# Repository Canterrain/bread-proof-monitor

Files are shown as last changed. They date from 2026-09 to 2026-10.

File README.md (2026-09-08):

# Bread Proof Monitor

A dough rise monitor that helps you know when it's time to fold, shape, or bake.

Place the sensor over your dough, choose a bread profile, and follow the rise from your phone. The monitor keeps track of progress, reminds you about folds, and can send a notification when your dough reaches its target.

Built for an ESP32 with a distance sensor and a temperature and humidity sensor. The dashboard runs on the monitor itself and opens in a browser on your home network.

## ✨ Features

- Live dough rise, elapsed time, temperature, and humidity
- Profiles for everyday breads, sourdough, pizza, rolls, and more
- Links to the recipes the profiles are based on
- Fold reminders for recipes with handling steps
- Separate bulk and final proof targets
- Optional phone alerts through ntfy: fold reminders, Ready to Shape, and Ready to Bake
- Pause and resume while you handle the dough
- Feedback that adjusts future targets for your recipe and setup
- Wi-Fi setup from your phone, with no credentials to put in the code
- Installation over USB from your browser

The targets are starting points. Flour, hydration, temperature, and starter or yeast strength all affect a proof. Use the reading alongside how your dough looks and feels.

## 🛠 Hardware

This project is designed around these specific boards and sensor modules:

- [ELEGOO 3PCS ESP-32 Dev Boards](https://amzn.to/46aN2Hq) (affiliate; one board needed)
- [HiLetgo SHT31-D Temperature and Humidity Sensor](https://amzn.to/4xLTMYm) (affiliate)
- [VL53L0X Time-of-Flight Ranging Sensor](https://amzn.to/4xEbyg1) (affiliate)

You'll also need:

- A USB data cable and USB power supply
- A container, and something that holds the distance sensor above the dough

That mount can be as simple as it sounds: the working prototype this project was developed on is just jumper-wired breakouts hot-glued or taped into a lid, on a stand of legs for containers that need one. No PCB is required to build or use this project.

The browser installer is for the original ESP32 chip. ESP32-C3, S3, and P4 boards need different firmware.

### Wiring

Both sensors share the same I²C bus:

| ESP32 | VL53L0X breakout | SHT31 breakout |
| --- | --- | --- |
| 3V3 | VIN / VCC | VIN / VCC |
| GND | GND | GND |
| **GPIO22** | **SDA** | **SDA** |
| **GPIO21** | **SCL** | **SCL** |

Use the pin labels on your particular breakout. This project's SDA and SCL assignments differ from the usual ESP32 defaults.

Mount the distance sensor securely above the dough with room for the tallest expected rise. Keep the sensor as close as that clearance allows. A long distance above a thin layer of dough makes small measurement changes look like much larger changes in rise.

### Optional: Rev A Carrier PCB

If you'd rather not hand-wire and hot-glue sensors into a lid, a custom carrier PCB is available as a drop-in alternative to the wiring table above — plug-in sockets for the ELEGOO EL-SM-012, ALAMSCN VL53L0X-V2, and HiLetgo GY-SHT31-D modules replace the loose wiring entirely. It's entirely optional; the software doesn't know or care which mounting approach you used. Its [KiCad files and manufacturing package](hardware/kicad/rev-a/README.md) are included — see the [hardware guide](guides/hardware.md) for ordering and assembly steps. The lid and enclosure design is still in progress, so even with the PCB you'll still need your own way to mount it.

## 🚀 Quick Start

### Install the software

Use Chrome, Edge, or a Firefox version with Web Serial support on a desktop or laptop. Safari and mobile browsers aren't supported by this installer.

1. Plug the ESP32 into your computer with a USB **data** cable.
2. Open the **[Bread Proof Monitor installer](https://canterrain.github.io/bread-proof-monitor/)**.
3. Click **Connect**, choose your board, and select **Install**.
4. For a first installation, select **Erase device**. Wait for installation to finish and the board to restart.

You don't need Arduino IDE to use the browser installer. If you'd rather build it yourself, see the [build guide](guides/development.md).

### Connect to Wi-Fi

1. Open your phone or computer's **Wi-Fi settings** and join **ProofMonitor-Setup**. The password is **sourdough**.
2. Open [http://192.168.4.1](http://192.168.4.1).
3. Choose your home Wi-Fi network and enter its password.
4. If you want phone alerts, copy the generated ntfy topic and subscribe to it in the ntfy app.
5. Save, wait for the monitor to restart, and reconnect your phone or computer to your home network.
6. Open **[http://proofmonitor.local](http://proofmonitor.local)**.

If that address doesn't open, use the monitor's IP address from your router's connected-device list.

## Using the Monitor

Choose a profile and apply its target. With the empty container and lid in their normal positions, press **Set Empty Setup**. Add the dough, let the lid settle, then press **Set Starting Dough Height**.

The dashboard shows the rise, time, and next step. When a fold is due:

1. Press **Pause Monitoring** before lifting the lid.
2. Fold the dough and put the lid back.
3. Press **Resume Monitoring**, allow the reading to settle, then press **Complete Step**.

When the target is reached, check the dough before pressing **Finish Proof**. For profiles with a monitored final proof, the monitor then prepares the Final stage. Most profiles ask you to calibrate the empty final-proof setup again before setting a new starting height.

Some recipes finish with refrigerated rests or stages that aren't useful to track by height. The monitor tells you when to continue with the linked recipe.

The [usage guide](guides/usage.md) covers calibration, pauses, re-baselining, target confirmation, and starting another batch.

## 🔔 Phone Alerts

Alerts use [ntfy](https://ntfy.sh/). Subscribe to the topic shown during setup to get fold reminders and Ready to Shape or Ready to Bake notifications.

The monitor generates a random topic for you. Treat that topic like a private link: anyone who knows it can subscribe or send messages to it. The dashboard works locally; delivering phone alerts requires internet access.

## Learning Your Dough

After each stage, rate the dough **Underproofed**, **Just Right**, or **Overproofed**, based on what you saw when that stage finished.

Two matching underproofed or overproofed ratings move that recipe and stage's suggested target by five percentage points. Adjustments stay within 25 points of the original suggestion. A Just Right rating clears the streak and keeps the adjustment.

Your feedback is saved on the device. Learned targets are used when you select a profile and when the monitor prepares Final proof. A proof keeps the target you've already applied. **Reset Learned Targets** clears the stored adjustments.

## Updating

Reconnect the ESP32 to your computer and use the same browser installer. For an update from this project's existing 4 MB / Huge APP layout, leave **Erase device** unchecked to retain saved settings. Erasing clears Wi-Fi, calibration, progress, the ntfy topic, and learned targets; repeat first-time setup afterward.

Update between proofs. Wireless updates aren't included.

## Development

The firmware uses Arduino for ESP32. See the [development guide](guides/development.md) for dependencies, local builds, and how to prepare a new browser-installable version.

| Path | What's there |
| --- | --- |
| `bread_proof_monitor.ino` | Startup and main loop |
| `app_state.*`, `proof_state.*` | Saved settings, rise calculations, and proof steps |
| `sensor_reader.*` | Distance, temperature, and humidity readings |
| `recipe_presets.*`, `outcome_feedback.*` | Profiles and learned target adjustments |
| `web_dashboard.*`, `web_assets.h` | Dashboard and setup pages |
| `notifications.*`, `wifi_setup.*` | Phone alerts and Wi-Fi |
| `docs/` | GitHub Pages installer and firmware files |
| `guides/` | Usage, development, and publishing instructions |
| `hardware/` | Carrier PCB design and manufacturing files |
| `tools/` | Local build, upload, and firmware packaging tools |

## Related Projects

- [Round Weather Display](https://github.com/Canterrain/round-weather-display), a round clock and weather display for Raspberry Pi or ESP32-P4
- [Weather Display](https://github.com/Canterrain/weather-display), a wider clock and weather display for under a cabinet or on a desk
- [Inky Planner](https://github.com/Canterrain/Inky-Planner), a daily planner for Raspberry Pi and Inky e-paper displays

## 📃 License

This project is licensed under the [Creative Commons Attribution–NonCommercial 4.0 International License](https://creativecommons.org/licenses/by-nc/4.0/). See [LICENSE](LICENSE). Third-party libraries retain their own licenses.

© 2026 Josh Hendrickson

Made by [Josh Hendrickson](https://anoraker.com)

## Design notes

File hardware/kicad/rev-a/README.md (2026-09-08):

# Rev A Carrier PCB

Reference documentation for the Bread Proof Monitor carrier PCB: a small board that gives the ESP32 module and both sensor breakouts a rigid, repeatable mount on the underside of a lid, using plug-in sockets instead of loose wiring.

## Status

- Schematic and PCB are complete. ERC: 0 errors, 0 warnings. DRC: 0 errors, 1 accepted cosmetic warning (see [Exclusions](#exclusions)).
- Routed at conventional prototype design rules — 0.25 mm trace, 0.6 mm/0.3 mm via, 0.2 mm clearance. No relaxed tolerances.
- All PCB-affecting mechanical decisions are finalized (VL53L0X optical alignment, SHT31 retention approach — see `mechanical-stackup.md`).
- Gerbers, drill files, and the full manufacturing package are generated and ready to order — see [Manufacturing Package](#manufacturing-package).
- Not yet designed: the lid/enclosure itself. Nothing here depends on it; see `mechanical-stackup.md` for the parametric interface (optical bore, vent pocket, standoff heights) it will need to satisfy.

## Bill of Materials

### Carrier-assembled (populated by the PCB assembly house)

| Ref | Part | Qty | Represents |
| --- | --- | ---: | --- |
| J1, J2 | Samtec `SSW-115-01-T-S` (1×15, 2.54 mm, THT) | 2 | Sockets the ELEGOO EL-SM-012 ESP32 module plugs into |
| J3 | Samtec `SSW-106-01-T-S` (1×6, 2.54 mm, THT) | 1 | Socket for the VL53L0X breakout |
| J4 | Samtec `SSW-104-01-T-S` (1×4, 2.54 mm, THT) | 1 | Socket for the SHT31 breakout |

J1 and J2 are the same physical part in two positions (a BOM grouped by MPN reports them as one line, qty 2). All four sockets are the same Samtec SSW family: 2.54 mm pitch, single-row, through-hole, lead-free (`-S`).

`U1` is a silkscreen/mechanical reference only for the ESP32 module's outline — zero pads, `in_bom=no`, `dnp=yes`. It never appears in a BOM export.

### User-installed (not part of the PCB order)

| Plugs into | Part | Amazon ASIN |
| --- | --- | --- |
| J1 + J2 | ELEGOO EL-SM-012 (ESP32 dev module) | B0D8T53CQ5 |
| J3 | ALAMSCN black VL53L0X-V2 breakout | B0DGL2P6XC |
| J4 | HiLetgo GY-SHT31-D breakout | B07ZSZW92J |

The EL-SM-012 plugs directly into J1/J2 using its own existing pin rows — nothing to solder. The VL53L0X-V2 and SHT31 breakouts (J3, J4) ship with loose 2.54 mm male header strips that need to be soldered onto the breakout before it plugs into the carrier.

## Pinout

### EL-SM-012 (ESP32 module) pin map

Verified directly against the [EL-SM-012 manual's pinout diagram](https://manuals.plus/asin/B0D8T53CQ5) (Section 5, Figure 5.1). Only the four pads below carry nets; the rest of the header exists for mechanical support only.

| Pad | Function | Pad | Function |
| ---: | --- | ---: | --- |
| 1 | VIN (5V) | 16 | **3V3** |
| 2 | **GND** | 17 | **GND** |
| 3 | GPIO13 | 18 | GPIO15 |
| 4 | GPIO12 | 19 | GPIO2 |
| 5 | GPIO14 | 20 | GPIO4 |
| 6 | GPIO27 | 21 | GPIO16 |
| 7 | GPIO26 | 22 | GPIO17 |
| 8 | GPIO25 | 23 | GPIO5 |
| 9 | GPIO33 | 24 | GPIO18 |
| 10 | GPIO32 | 25 | GPIO19 |
| 11 | GPIO35 | 26 | **GPIO21 (SCL)** |
| 12 | GPIO34 | 27 | GPIO3 (RX0) |
| 13 | GPIO39 (VN) | 28 | GPIO1 (TX0) |
| 14 | GPIO36 (VP) | 29 | **GPIO22 (SDA)** |
| 15 | EN | 30 | GPIO23 |

**Warning:** pad 1 is VIN — raw 5V from USB — not 3V3. Only pads 16 (3V3) and 17 (GND) feed the sensor rail; both sensors are 3.3V-only parts. All four connected pads (3V3, GND, SDA, SCL) sit on the same header column (16-30); the other column (1-15) carries no nets on this board.

The GPIO22 → SDA / GPIO21 → SCL assignment is a firmware convention, not a hardware requirement — it matches the wiring already used by the ESP32 sketch itself. The EL-SM-012's own silkscreen shows a different default for the Wire library; this board's net assignment intentionally overrides that default.

### Connector and mounting-hole reference

`LID_ORIGIN` (0, 0) is the geometric center of the dough/container reference plane, and doubles as `TOF_ORIGIN` — the VL53L0X's optical axis is placed exactly there by construction (J3 is rotated 180° so its optical center, not its mounting-hole midpoint, lands on the datum). Coordinates below are relative to `LID_ORIGIN`; +X toward the antenna notch, +Y toward the ESP32 header.

| Feature | Coordinate (mm) | Notes |
| --- | ---: | --- |
| J3 (VL53L0X) mounting holes | (-10, -2.2) / (+10, -2.2) | Hole-midpoint sits at (0, -2.2), not `LID_ORIGIN` — the sensor's actual optical axis is what's aligned to the datum instead |
| J4 (SHT31) footprint origin (pin 1 / VIN) | (0, -29) | Not a mechanical datum. Retention is a lid/enclosure pocket-clip, not a PCB feature |
| U1 (ESP32 module outline) footprint origin | (0, +27) | Mechanical reference only, not a BOM item |
| J1 / J2 (ESP32 carrier sockets) | (-17.78, +14.18) / (-17.78, +39.82) | Local pin 1 of each |
| MH1 / MH2 / MH3 (carrier mounting holes) | (+40, 0) / (-40, 0) / (0, -45) | 3.2 mm NPTH, M3 clearance, provisional pending host hardware |

## Board Outline

A circle with a USB-C access notch and an antenna overhang notch, rather than a plain circle or a custom polygon — a plain circle large enough to clear the ESP32 module would need to be bigger still and wouldn't give cable/antenna clearance on its own.

- **Base circle:** radius 52 mm, centered on `LID_ORIGIN`. Overall envelope: X/Y from -52.0 to +52.0 mm (~104 × 104 mm).
- **USB-C notch:** board material stops at X = -25 mm, open from there to the edge across Y = 17-37 mm. The EL-SM-012's USB-C connector sits just past this cut, fully in open air.
- **Antenna notch:** board material stops at X = +21 mm, open across the same Y range, 3.22 mm past J1/J2's last pin — giving the WROOM antenna genuine physical overhang rather than relying only on a copper keepout.
- The board's lower size bound is the EL-SM-012 module's own footprint (51.74 × 29.00 mm); its farthest structurally-needed corner sits 50.3 mm from `LID_ORIGIN`, leaving a 1.7 mm margin at the 52 mm radius.

## Antenna Clearance

- `ESP32_ANTENNA_KEEP_OUT`, on both F.Cu and B.Cu: X 9-65 mm, Y 15-39 mm (56 × 24 mm) — no tracks, vias, or zone fills permitted inside it.
- Board material itself ends at X = 21 mm (the antenna notch above), so this region has no FR4 at all, not just no copper.
- The SDA trace's closest approach (pad 29, local X = +15.24 mm) jogs into its routing lane above the header row before heading down the board, so it never enters the keepout's Y band.

## Routing

- **Shared trunks, not per-destination lanes.** 3V3, SDA, and SCL each get one trunk from J2, which tees off to J3 and continues to J4 — not a separate trunk per destination. This keeps routing to 3 lanes at conventional design rules.
- **GND has no explicit trace.** J2, J3, and J4's GND pads are through-hole and sit directly inside the filled F.Cu/B.Cu ground pours; three stitching vias tie the two copper layers together away from the signal corridor. Verified directly against KiCad's own connectivity graph (not inferred from geometry) — J2's GND pad and both sensors' GND pads resolve to the same connected copper network.
- All routing lives on B.Cu, with a handful of via hops to F.Cu to resolve a few crossings.
- 15 vias total: 12 signal-routing detour vias (3V3 ×8, SCL ×4, SDA ×0) plus 3 GND stitching vias. Minimum via-to-via spacing: 0.7 mm edge-to-edge.

## Mechanical Clearances

No copper or courtyard overlap anywhere on the board:

- J1 (top, nearest neighbor to J3) to J3 (bottom): 3.93 mm Y gap.
- J3 to J4 (both bottom): 4.60 mm Y gap.

## Exclusions

1. **Silkscreen clipped by the board edge** — U1's own reference outline rectangle on F.SilkS is clipped at the USB-C notch, since the real EL-SM-012 module genuinely overhangs that cutout by design. Cosmetic only; has no fabrication impact.

## Manufacturing Package

`RevA_Manufacturing_2026-08-26/` contains the complete fabrication and assembly output — Gerbers, Excellon drill files with maps and a report, the final assembly BOM, a placement/position file, a fabrication drawing, and `RevA_Gerbers_NextPCB.zip` (Gerbers + drill files pre-zipped for direct upload to NextPCB's quote tool). See that directory's own `README.md` for the full contents list, fabrication notes, and its change history.

## References

- [EL-SM-012 manual and dimensional drawing](https://manuals.plus/asin/B0D8T53CQ5) — pinout diagram in Section 5, Figure 5.1
- [HiLetgo GY-SHT31-D product listing, ASIN B07ZSZW92J](https://www.amazon.com/dp/B07ZSZW92J)
- [ALAMSCN VL53L0X-V2 product listing, ASIN B0DGL2P6XC](https://www.amazon.com/dp/B0DGL2P6XC)

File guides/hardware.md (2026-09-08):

# Ordering and Building the Carrier PCB

[Back to the project](../README.md)

This covers getting a Rev A carrier PCB made and turning it into a working sensor mount. For the board's full technical reference (pinout, dimensions, design rules, verification results), see [`hardware/kicad/rev-a/README.md`](../hardware/kicad/rev-a/README.md).

The lid and enclosure this carrier mounts into aren't designed yet, so this guide stops at a working, bench-wired sensor mount rather than a finished physical unit.

## 1. Order the PCB

The fabrication files are in [`hardware/kicad/rev-a/RevA_Manufacturing_2026-08-26/`](../hardware/kicad/rev-a/RevA_Manufacturing_2026-08-26/). It's a conventional 2-layer board at standard prototype tolerances — no special fabrication options are needed.

- **Bare board only:** upload `RevA_Gerbers_NextPCB.zip` (or the `gerbers/` and `drill/` folders directly) to your fab house's quote tool. You'll receive an unpopulated board and need to hand-solder the four sockets yourself — see the carrier-assembled parts table in [`hardware/kicad/rev-a/README.md`](../hardware/kicad/rev-a/README.md#bill-of-materials) (or `bom/RevA_assembly_BOM.csv` directly) for the exact Samtec part numbers.
- **Board with sockets pre-assembled:** if your fab offers PCB assembly (NextPCB does), upload the Gerbers/drill files for fabrication and also supply `bom/RevA_assembly_BOM.csv` and `position/RevA_placement.csv` for the assembly step. All four sockets are through-hole, so hand or wave soldering is the expected assembly method — a pick-and-place file has limited value here, but it's included for completeness.

Either way, you're only ordering and paying for the bare carrier board and its four sockets — the ESP32 module and both sensor breakouts are never part of this order.

## 2. Buy the plug-in modules

These are ordinary off-the-shelf parts, bought separately from wherever you like:

| Plugs into | Part | Amazon ASIN |
| --- | --- | --- |
| J1 + J2 | ELEGOO EL-SM-012 (ESP32 dev module) | B0D8T53CQ5 |
| J3 | ALAMSCN black VL53L0X-V2 breakout | B0DGL2P6XC |
| J4 | HiLetgo GY-SHT31-D breakout | B07ZSZW92J |

## 3. Prepare the sensor breakouts

The VL53L0X and SHT31 breakouts ship with loose 2.54 mm male header strips, not pre-soldered pins. Solder a header onto each one before it can plug into the carrier.

The EL-SM-012 needs no preparation — it already has its own male pin rows fixed to the module and plugs straight into J1/J2.

## 4. Assemble

1. Plug the EL-SM-012 into the J1/J2 sockets (top side of the carrier).
2. Plug the VL53L0X breakout into J3 (underside).
3. Plug the SHT31 breakout into J4 (underside), sensing element facing outward.

**Before powering on, double-check orientation on all three.** These are plain single-row headers into single-row sockets — nothing mechanically prevents a shifted or reversed insertion. Confirm each module's pin 1 lines up with its socket's pin 1 against the board's silkscreen. Getting this wrong on the ESP32 module in particular can put 5V (VIN) where the sensors expect 3.3V.

## 5. Mount to a lid

Carrier mounting holes MH1-MH3 (3.2 mm NPTH, M3 clearance) are in place for this, but the lid/enclosure design that uses them isn't finished. Until it is, this is a DIY step — see [`mechanical-stackup.md`](../hardware/kicad/rev-a/mechanical-stackup.md) for the parametric interface (optical bore, vent pocket, standoff heights) any lid design needs to satisfy, and the wiring table in the main [README](../README.md#wiring) for a non-PCB mounting approach in the meantime.

## 6. First power-up

Once assembled, treat it like any other Bread Proof Monitor board: follow the main README's [Quick Start](../README.md#-quick-start) to install the firmware over USB and connect it to Wi-Fi.

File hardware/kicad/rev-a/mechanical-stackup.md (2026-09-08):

# Rev A Mechanical Stack-up — Sensor Interfaces

Status: **Rev A PCB-affecting mechanical decisions are finalized.** The
VL53L0X optical XY alignment, SHT31 retention approach, and P_sensor
nominal are all settled and reflected in the fabricated copper (§1, §2,
§3). Lid thickness and enclosure geometry remain **parametric** — every
dimension that depends on the lid is still expressed as a formula, not a
fixed number, since the lid itself is not yet designed. Gerbers are
generated this pass; lid CAD is not.

**Hardware identities (established outside this task — used as-is, not
re-researched here):**

| Module | Exact part | Amazon ASIN |
| --- | --- | --- |
| ESP32 | ELEGOO EL-SM-012 | B0D8T53CQ5 |
| VL53L0X | ALAMSCN black VL53L0X-V2 | B0DGL2P6XC |
| SHT31 | HiLetgo GY-SHT31-D | B07ZSZW92J |

**Architecture note — removable plug-in modules, not soldered to the
carrier.** ESP32, VL53L0X, and SHT31 are all plug-in modules: female
Samtec SSW sockets are soldered to the carrier PCB (J1 + J2:
`SSW-115-01-T-S`, 1x15 each, one per ESP32 pin row; J3: `SSW-106-01-T-S`,
1x6; J4: `SSW-104-01-T-S`, 1x4 — 2.54 mm pitch, single-row, through-hole,
lead-free solderable). U1 itself is the ESP32 module's mechanical outline
only — zero pads, not a BOM/assembly item; the module is user-installed,
plugging into J1/J2, not procured or soldered by the assembly house. The
sensor-side male pins are the loose 2.54 mm
header strips already supplied with the exact ALAMSCN VL53L0X-V2 and
HiLetgo GY-SHT31-D modules — not a separately selected or premium
replacement part. Each breakout plugs into its socket and is additionally
mechanically retained by the M2.5 standoff/screw system (§3.1) — except
SHT31, which uses a lid/enclosure pocket-clip instead (§2.3, Rev 7). No
sensor board is soldered directly to the carrier.

**Rev 2 — corrections applied in that pass:** the VL53L0X optical bore is
no longer a precise Ø3.0 mm hole centered on the mounting-hole midpoint
(§1.5, historical); the Z-stack no longer lets a standoff "independently"
set the sensor board's height while the connector "just tolerates" it
(§3); `G_top`/`H_lid`/`D_far = G_top + H_lid` are defined separately, and
the bore is sized at `D_far`, not `G_top`.

**Rev 3 — corrections applied in that pass:** the mounting-hole midpoint
was no longer called `TOF_ORIGIN` while also being ~2.1 mm from the real
optical axis — three separate datums (`LID_ORIGIN`, `J3_MOUNT_ORIGIN`,
`TOF_ORIGIN`) are now named explicitly (§1.1); `P_sensor` (VL53L0X package
protrusion below the breakout board) was introduced so Standoff B accounts
for it (`Standoff_B_J3 = P_sensor + G_top`, `L_total_J3 = H_conn + t_board
+ P_sensor + G_top`), while `D_far = G_top + H_lid` stays unchanged since
it's already referenced from the optical face directly.

**Rev 4 — corrections applied in this pass:**

1. **Removed the unsupported `H_conn = 2.5 mm` assumption.** That number
   was a "low-profile socket" placeholder invented for lack of a selected
   part. It's gone. `H_conn` is now carried **symbolically** through every
   formula and worked example until the real connector-pair geometry is
   known (§3.0, §3.1).
2. **Named the current preferred carrier-side socket family**: Samtec
   `CES-106-01-G-S` (J3, 1×6) and `CES-104-01-G-S` (J4, 1×4) — 2.54 mm
   pitch, single-row, through-hole, closed-entry, low-profile. Their
   published mechanical drawing gives a **5.08 mm socket body height**.
3. **That body height is explicitly not `H_conn`.** `H_conn` is the
   carrier-PCB-underside-to-breakout-board-top distance *once the actual
   mating male header is fully and correctly seated* — a function of the
   male header's own geometry and insertion depth, not of the socket
   alone. Until a matching male header is selected, `H_conn` stays
   unresolved (§3.1).
4. Made every dependent Z-stack formula parametric in `H_conn` rather
   than substituting a specific value for it.

**Rev 5 — correction applied in this pass:**

5. **Removed the intentionally-undersized `Standoff A = H_conn − c`
   model.** A rigid M2.5-screw-clamped standoff cut deliberately shorter
   than the connector's own mated height isn't a tolerance mechanism —
   tightening the screw would have to flex a PCB, preload the connector's
   pins, or leave the stack not actually clamped, to close that gap.
   `Standoff_A_nominal = H_conn` now — the connector establishes the
   seated Z position, and the mechanical support nominally meets the
   breakout at that same plane, no built-in offset. Real tolerance
   accommodation (spacer tolerancing, a compliant washer, shoulder-style
   retention, a rocking-only clip, or similar) is left as an open
   mechanical-detail decision, not invented here (§3.1).
6. **Corrected the framing of the remaining connector task.** The sensor
   breakouts already carry standard 2.54 mm male header interfaces — the
   HiLetgo GY-SHT31-D ships with its own male header strip soldered to the
   board, and the VL53L0X breakout's footprint already reflects the same
   kind of standard header pins. There is no header *family* left to
   choose. What remains is establishing the **actual mated geometry**
   (and the resulting `H_conn`) between those standard pins and the
   carrier-side socket (§3.1).

**Rev 6 — connector decision finalized, this pass:**

7. **Selected carrier-side sockets: Samtec SSW, not CES.** The Rev 4/5
   Samtec CES consideration is superseded. The selected parts are
   `SSW-115-01-T-S` (J1 + J2, 1x15 each, qty 2 — one per ESP32 pin row;
   U1 itself is the ESP32 module's mechanical outline, not a socket),
   `SSW-106-01-T-S` (J3, 1x6), and `SSW-104-01-T-S` (J4, 1x4) — 2.54 mm
   pitch, single-row, through-hole, lead-free solderable (`-S` row
   option). Sensor-side male pins are the loose header strips already
   supplied with the ALAMSCN VL53L0X-V2 and HiLetgo GY-SHT31-D modules —
   no replacement premium header, per instruction, unless a real fit
   problem is found.
8. **`H_conn` is resolved: `H_conn_nominal = 11.05 mm`** for the selected
   SSW stack (J3/J4). This number comes from the connector-stack decision
   made outside this document, not re-derived here. `Standoff_A_nominal =
   H_conn = 11.05 mm` (§3.1) — no longer symbolic. Everything downstream
   (`Standoff_B_J3`, `L_total_J3`) is now a concrete worked example, not
   an illustrative placeholder.
9. **KiCad footprints checked against the Samtec SSW/SSQ published
   mechanical drawing** (2.54 mm pitch; body length = `2.54mm x N +
   0.51mm`) and against KiCad's own verified standard 2.54 mm THT
   pin-socket land pattern (1.0 mm drill). The existing generic J3 and J4
   footprints were found dimensionally correct as-is — reused, not
   replaced. The former combined `ESP32_EL_SM_012_CARRIER_2x15` footprint
   (30 pads, doubling as both the ESP32 module's mechanical outline and
   its two real carrier sockets) was subsequently split — in the
   follow-on BOM-model cleanup, not re-derived here — into
   `ESP32_EL_SM_012_MODULE_OUTLINE` (U1: mechanical-only, zero pads, not
   a BOM item) plus two placements of a new `SSW-115-01-T-S_1x15`
   footprint (J1, J2: the real carrier sockets), at the exact same pad
   coordinates the combined footprint used. See
   `RevA_Sensors.pretty/*.kicad_mod` `descr` fields and the PCB build for
   the specific numbers checked, and the project README's "BOM model"
   section for the full J1/J2/U1 rationale.

**Rev 7 — Rev A PCB-affecting decisions finalized, this pass:**

10. **VL53L0X optical XY alignment resolved: `TOF_ORIGIN = LID_ORIGIN` by
    construction, not by hoping the offset is small.** The Rev A nominal
    optical offset is set to **2.2 mm** (the ALAMSCN listing-photo
    measurement of 2.12 mm, §1.2, corroborated by an independent direct
    measurement of a common GY-VL53L0XV2 board). Rather than shifting J3
    by +2.2 mm in Y — which would have moved it *toward* J1 and eaten
    into the ~1.7 mm J1/J3 courtyard clearance that existed at the time —
    J3 is **rotated 180°** and placed so its mounting-hole midpoint moves
    to `Y = -2.2 mm`, landing the *optical* axis on `LID_ORIGIN` instead.
    Footprint origin `(10, -2.2)`, rotation `180°`. Verified against
    KiCad's own applied transform, not just hand-derived (§1.3): resulting
    `J3_MOUNT_ORIGIN = (0, -2.2)`, `TOF_ORIGIN = (0, ~0) = LID_ORIGIN`,
    mounting holes at `(+10, -2.2)` and `(-10, -2.2)`. A side effect of
    the rotation (not just the shift) is that J3's courtyard now sits
    *farther* from J1 than before (§3.2/README), not closer — the
    original concern is fully addressed, not just avoided.
11. **SHT31 retention resolved: lid/enclosure pocket-clip, not a PCB
    hole.** Rev A does not add a carrier PCB retention hole for J4; the
    footprint's `PRELIM: VERIFY RETENTION HOLE` fab annotation and its
    associated candidate-hole graphic are removed (they no longer apply
    and would misleadingly imply PCB fabrication depends on them). J4's
    board envelope and socket geometry are otherwise unchanged (§2.3).
12. **`P_sensor` finalized as a Rev A nominal, not a PCB hold.**
    `P_sensor_nominal = 1.0 mm` (ST's published VL53L0X package height —
    the package is `4.4 × 2.4 × 1.0 mm`). Normal solder/assembly
    tolerance around this value is an enclosure/standoff tolerance
    question, not something that affects Rev A copper or placement.
13. **Breakout PCB thickness (`t_board`) reclassified as an
    enclosure-fit parameter, not a PCB hold** — it was never part of Rev A
    copper or placement, only of the (still-parametric, still-undesigned)
    lid/standoff stack-up.
14. **The PCB fabrication-hold list is now empty.** See "Remaining
    fabrication holds" below — everything that used to block Gerber
    generation is resolved. What's left are enclosure/mechanical
    fit-check items that the lid design will eventually want, none of
    which hold this PCB.

## 1. VL53L0X-V2 (J3) — optical package location

### 1.1 Datums — three separate points, now two of them coincide by design

This design has three distinct reference points that must not be
conflated, even though (as of Rev 7) two of them are now deliberately
made to coincide:

| Datum | Meaning | Current value | Status |
| --- | --- | --- | --- |
| **`LID_ORIGIN`** | The intended measurement point over the dough — the fixed reference everything else is judged against. | `(0, 0)` | Fixed, by definition — doesn't move. |
| **`J3_MOUNT_ORIGIN`** | Midpoint of J3's two M2.5 retention holes (20.0 mm apart). | `(0, -2.2)` | **Fixed by the Rev 7 footprint placement** (origin `(10,-2.2)`, rotation `180°`). No longer coincident with `LID_ORIGIN` — that trade was made deliberately so the *optical* axis, not the hole-midpoint, lands on the datum that actually matters. |
| **`TOF_ORIGIN`** | The VL53L0X's actual optical (emitter/receiver) axis. | `≈ (0, 0) = LID_ORIGIN` | **Achieved by construction (Rev 7)**, using the 2.2 mm Rev A nominal offset (§1.2/§1.3). Nominal, not caliper-verified against the exact physical part in hand — but no longer a PCB-blocking hold; residual error, if any, is well within the lid opening's built-in margin (§1.4). |

**Rev A achieved state** (verified against KiCad's own applied
position+rotation transform, not just hand-derived — §1.3):

```
J3_MOUNT_ORIGIN = (0, -2.2)          -- no longer at LID_ORIGIN
TOF_ORIGIN      = (0, ~0) = LID_ORIGIN   -- this is what's aligned now
```

Sections 1.4 onward say `TOF_ORIGIN` when they mean the optical axis and
`LID_ORIGIN`/`J3_MOUNT_ORIGIN` when they mean the fixed measurement point
or the hole geometry — the three are still not interchangeable, even
though `TOF_ORIGIN` and `LID_ORIGIN` now coincide.

- **Fixed by the footprint (exact):** the two M2.5 retention holes are
  20.0 mm apart. As of Rev 7 their midpoint (`J3_MOUNT_ORIGIN`) sits at
  `(0, -2.2)`, not at `LID_ORIGIN`. The two-hole rigid retention itself
  (geometry, hole size) is unchanged — only where it's placed moved.
- **Measured (§1.2):** the VL53L0X module's package outline position
  relative to those two holes, from the ALAMSCN listing's own product
  photography — this is what located `TOF_ORIGIN` and set the 2.2 mm Rev
  A nominal.
- **Still nominal, not caliper-verified:** the exact optical
  (emitter/receiver) centroid *within* the package outline. ST's VL53L0X
  datasheet gives the package size precisely (4.40 x 2.40 x 1.00 mm,
  "Optical LGA12") but does not publish the emitter/collector centroid
  offset from the package edge as a text-extractable dimension. Treating
  the package's geometric center as `TOF_ORIGIN` is a reasonable
  approximation, corroborated by an independent measurement of a common
  GY-VL53L0XV2 board — good enough confidence to commit to fabrication,
  not the same as a caliper/microscope measurement of the exact part in
  hand.

### 1.2 Measured offset from the ALAMSCN listing photos

The ALAMSCN listing (ASIN B0DGL2P6XC) product photography includes a
straight-on shot of the sensor-chip side of the board, silkscreened
`VL53L0/1XV2`, with a white rectangle marking the sensor module's own
footprint. Both mounting holes and the rectangle are clearly resolved.
Measuring directly from that image (hole spacing = 20.0 mm used as the
pixel-to-mm scale reference):

| Quantity | Value |
| --- | ---: |
| Measured module outline size | 4.92 x 2.83 mm (vs. ST's nominal 4.40 x 2.40 mm package — consistent, silkscreen courtyard is drawn slightly oversized) |
| `TOF_ORIGIN`, X, relative to `J3_MOUNT_ORIGIN` (pre-Rev-7 hole placement) | **-0.09 mm** (i.e. centered — within measurement noise) |
| `TOF_ORIGIN`, Y, relative to `J3_MOUNT_ORIGIN` (pre-Rev-7 hole placement) | **-2.12 mm** (offset away from the 6-pin header, toward the "blank" end of the board) |

In the footprint's own local frame (holes at local (0,0)/(20,0), header
pins at local Y=+5.35): `TOF_ORIGIN` sits at approximately local
**(10, -2.1)** — i.e. right at `J3_MOUNT_ORIGIN` in X, and about 2.1 mm
toward the header-free end in Y. **Rev A nominal, used for the placement
in §1.3, rounds this to 2.2 mm**, corroborated by an independent direct
measurement of a common GY-VL53L0XV2 board (not the exact ALAMSCN part,
but close geometry, done outside this document).

**Confidence:** this is measured from the exact listing's photography
(not a generic proxy board), so it's a real, specific data point — but it
is still a photo measurement, not a caliper or microscope measurement of
the physical part. Two independent sources now agree closely enough to
commit to fabrication (Rev 7) — see the fabrication-holds list for the
residual, non-blocking follow-up.

### 1.3 Rev A implementation — J3 rotated 180°, `TOF_ORIGIN` on `LID_ORIGIN`

**The problem with the obvious fix.** The naive correction — shift J3 by
+2.2 mm in Y, leaving its orientation alone — moves `J3_MOUNT_ORIGIN` (and
therefore J3's whole footprint, including its courtyard) *north*, i.e.
*toward* J1 (the ESP32 carrier socket immediately above it). At the time
this decision was made the J1/J3 courtyard gap was only ~1.7 mm; a
straight +2.2 mm shift would have consumed all of that margin and then
some. **Rejected for that reason.**

**The Rev 7 fix: rotate 180°, don't just translate.** The footprint's
local geometry is fixed: mounting holes at local `(0,0)` and `(20,0)`,
`J3_MOUNT_ORIGIN` at local `(10,0)`, optical package (`TOF_ORIGIN`) at
local `(10,-2.2)` (§1.2's measurement, rounded to the Rev A nominal).
Placing the footprint origin (anchor = local `(0,0)`) at global `(10,
-2.2)` with a `180°` rotation:

```
rotated_local(x,y) = (-x,-y)                     [180° about the anchor]
global(p)          = anchor + rotated_local(p)

J3_MOUNT_ORIGIN  (local 10,0):    (10,-2.2) + (-10, 0)  = (0, -2.2)
TOF_ORIGIN       (local 10,-2.2): (10,-2.2) + (-10, 2.2) = (0, 0)  = LID_ORIGIN
hole 1 (local 0,0):               (10,-2.2) + (0, 0)     = (10, -2.2)
hole 2 (local 20,0):              (10,-2.2) + (-20, 0)   = (-10, -2.2)
```

**Verified against KiCad's own applied transform after placement, not
just this hand derivation** — independently reconstructing pcbnew's
actual position+orientation transform and mapping the same local points
through it:

```
placed footprint anchor:  (10.0, -2.2) mm, orientation 180.0°
hole 1 (actual pad):      (10.0, -2.2) mm
hole 2 (actual pad):      (-10.0, -2.2) mm
J3_MOUNT_ORIGIN (midpoint of actual holes): (0.0, -2.2) mm
TOF_ORIGIN (local (10,-2.2) mapped through the SAME transform): (0.0, ~0.0) mm
```

The optical axis lands on `LID_ORIGIN` to floating-point precision. A
useful side effect of rotating (not just translating): J3's courtyard
shape is now oriented the *other* way too, so the net result is J3 moved
*away* from J1 overall (courtyard gap grew, §3.2/README), not toward it —
the original concern that ruled out the naive shift doesn't apply to the
rotation.

**Pin mapping is unaffected by the rotation.** J3's pin-to-net assignment
is a schematic-level fact, untouched by this PCB-only placement change:
pin 1 = 3V3, pin 2 = GND, pin 3 = SCL/GPIO21, pin 4 = SDA/GPIO22, pin 5
(GPIO1) and pin 6 (XSHUT) = NC. Only the physical *location* of those pins
moved (and, because of the 180° rotation, their X-ordering reversed and
their row moved from the north side of the mount holes to the south side)
— routing was rerouted to reach the new positions (README "Routing"), but
no net assignment changed.

### 1.4 Rev A final lid opening geometry

Three separate lengths matter here, and they must not be conflated:

- **`G_top`** — air gap from the sensor's optical face (`TOF_ORIGIN`)
  down to the lid's **top** (near, sensor-side) surface.
- **`H_lid`** — lid thickness (parametric, independent material choice).
- **`D_far = G_top + H_lid`** — distance from `TOF_ORIGIN` down to the
  lid's **chamber-side (far)** surface.

VL53L0X full field of view is **25°** (ST datasheet: "VL53L0X system FOV
is 25 degrees" / half-angle 12.5°), unchanged by cover glass choice (see
1.6). For a straight cylindrical bore of constant diameter, the FOV cone
is widest at the **far** end, so `D_far` — not `G_top` — is what must size
the bore:

```
opening_diameter(H_lid) = 2 · D_far · tan(12.5°) + margin
                         = 2 · (G_top + H_lid) · tan(12.5°) + margin
```

using `G_top = 1.5 mm` (target) and `margin = 1.0 mm` total:

| H_lid | D_far = G_top + H_lid | Bore Ø (centered exactly on `LID_ORIGIN`, = `TOF_ORIGIN` as of Rev 7) |
| ---: | ---: | ---: |
| 2.0 mm | 3.5 mm | 2.6 mm |
| **3.0 mm** | **4.5 mm** | **3.0 mm** |
| 4.0 mm | 5.5 mm | 3.4 mm |
| 5.0 mm | 6.5 mm | 3.9 mm |

**This is now the live spec, not a conditional future one.** Because J3
is physically rotated/repositioned so `TOF_ORIGIN = LID_ORIGIN` (§1.3),
this bore can be cut centered on `LID_ORIGIN` directly — the earlier
"provisional oversized opening, offset from `LID_ORIGIN`" approach (old
§1.5, kept below as historical record) is superseded and no longer
needed. This table does not depend on `H_conn` at all — the optical-bore
sizing and the connector question are independent.

**Recommendation: minimize `G_top`.** A small `G_top` keeps `D_far` (and
therefore the bore) small — good for a clean chamber-facing surface, a
minimal steam/condensate ingress path, and a short response time. Target
**`G_top` = 1.5 mm**.

### 1.5 Historical: the pre-Rev-7 provisional opening (superseded)

Before Rev 7, the PCB kept `J3_MOUNT_ORIGIN = LID_ORIGIN` and `TOF_ORIGIN`
was ~2.1-2.2 mm away, unresolved. Because a final-spec bore's own radius
(~1.5 mm) was smaller than that offset, a precision bore centered on
`LID_ORIGIN` would have risked missing the sensor's real field of view —
so two placeholder options were defined for a first fit-check lid only:
**Option A**, an oversized (~Ø5.0 mm at `H_lid`=3mm) opening centered on
the *estimated* `TOF_ORIGIN` rather than `LID_ORIGIN`; **Option B**, a
fully direction-agnostic Ø9.5 mm opening centered on `LID_ORIGIN` for a
team unwilling to trust even the measured offset's direction. **Both are
superseded by Rev 7** (§1.3/1.4) — `TOF_ORIGIN` now *is* `LID_ORIGIN` by
construction, so the final-spec bore (§1.4) applies directly. Kept here
only as a record of the reasoning that preceded the Rev 7 fix.

### 1.6 Cover glass — avoid unless necessary

Per the brief, default to **no cover** over the VL53L0X opening — a bare
through-hole, open to the chamber:

- **Ranging offset shift.** ST's guidance: a cover window changes the
  ranging offset and needs recalibration.
- **Cross-talk.** A cover glass reflects some VCSEL output back into the
  receiver, reducing usable range.

**When a cover would become necessary:** if condensation or flour dust
ingress into the electronics bay turns out to be a real problem. If so,
the fix is a thin (0.5-1 mm) IR-transparent window bonded at the lid's
chamber-side surface, sized to the bore diameter from 1.4, with the
offset/cross-talk recalibration noted as a required follow-up. Open
decision, not resolved here.

## 2. SHT31 (J4) — ventilated pocket, lid/enclosure retention

J4 is the exact **HiLetgo GY-SHT31-D (ASIN B07ZSZW92J)** established for
this project — not re-researched or substituted in this pass.

### 2.1 Location — unchanged

J4 stays at its established placement (footprint origin / pin 1 / VIN at
**(0, -29)** relative to `LID_ORIGIN`), clear of the VL53L0X optical path
and clear of J3's hardware by a de-risked margin (recomputed against the
Rev 7 J3 placement — see README "Mechanical: top vs. bottom overlap" for
the current J3/J4 clearance number). No placement change in this pass.

### 2.2 Ventilated pocket concept

The SHT31's sensing element is a capacitive RH + temperature die on the
underside of the small breakout board — unlike the VL53L0X, it has no
aiming requirement, just needs representative chamber air to reach it
without pooling condensate on the die. Proposed pocket, sized to the
board's real outline (10.7 x 13.1 mm per the existing footprint
annotation):

- A shallow rectangular **recess** in the lid's chamber-side face, sized
  to the board's real outline plus ~0.5 mm clearance per side, deep enough
  to seat the board's retention feature (see 2.3) flush or slightly
  recessed — not proud of the lid.
- **Vent pattern**, not a single large opening: 6-8x Ø1.5 mm holes
  positioned under the sensing-element half of the board, clear of the
  retention feature.
- **Orientation:** vent pattern on the chamber-facing surface, not the
  side — avoids being a direct drip target.
- Multiple small holes over one big opening: keeps any single opening too
  small for a condensate droplet to bridge, still gives enough open area
  for reasonable RH response, and leaves most of the recess floor solid
  for retention.

### 2.3 Mechanical retention — resolved (Rev 7): lid/enclosure pocket-clip

**Rev A uses the hard lid pocket/clip retention option, not the
breakout's own mounting hole.** This closes what was previously an open
PCB-adjacent fabrication hold:

- **No carrier PCB retention hole for J4.** None is added in Rev A, and
  none was ever strictly required for this option — the retention feature
  lives entirely in the lid/enclosure.
- **The footprint's `PRELIM: VERIFY RETENTION HOLE` annotation and its
  candidate-hole graphic are removed** (Rev 7) — they described a design
  path Rev A isn't taking, and left in place would misleadingly suggest
  PCB fabrication depended on resolving them. The footprint now carries a
  `RETENTION: LID/ENCLOSURE POCKET-CLIP (NOT A PCB HOLE)` note instead.
- **J4's board envelope and socket geometry are unchanged** — the pocket
  concept from §2.2 (recess sized to the board outline + clearance, vent
  pattern in the floor) still applies; only the *retention* mechanism
  (tabs/ribs molded into the lid, gripping the board's edges) is now
  settled, per §3.1's same Z-stack model (the tabs are positioned at the
  connector's mated height, `H_conn`, same constraint a standoff would
  have had).
- **This is now an enclosure/lid-CAD item, not a PCB item.** The exact
  tab/rib geometry is still undesigned (lid CAD hasn't started — see
  status line at top), but nothing about it requires a carrier PCB
  change, so it does not hold Gerber generation.

(SHT31's own sensing die is assumed to sit at the breakout board's
underside — no separate `P_sensor`-style package protrusion is modeled
for it; low stakes given the retention mechanism no longer depends on
board-hole registration.)

## 3. Full stack-up (top/outside to bottom/inside)

All Z dimensions are relative to the carrier PCB's own top surface (Z=0),
positive Z upward, negative Z downward (toward the lid/chamber side). See
§1.1 for the `LID_ORIGIN`/`J3_MOUNT_ORIGIN`/`TOF_ORIGIN` datums.

### 3.0 Key parameters

| Symbol | Meaning | Status |
| --- | --- | --- |
| `t_carrier` | Carrier PCB thickness | Fixed: 1.6 mm (existing PCB) |
| `H_conn` | Female socket → mated standard male header → breakout board's top surface, fully and correctly seated: carrier PCB underside to breakout board top | **Resolved (Rev 6): `H_conn_nominal = 11.05 mm`.** Carrier-side socket selected — Samtec `SSW-106-01-T-S` (J3, 1×6) / `SSW-104-01-T-S` (J4, 1×4), 2.54 mm pitch, single-row, THT, lead-free solderable. Mated with the loose male header strips already supplied with the ALAMSCN and HiLetgo modules. `H_conn_nominal` comes from the connector-stack decision made outside this document. |
| `t_board` | Sensor breakout board thickness (J3, J4) | **Enclosure-fit parameter (Rev 7), not a PCB hold** — doesn't affect Rev A copper or placement, only the (still-undesigned) lid/standoff stack-up. Provisional value: 1.3 mm (typical small 2-layer FR4), assumed equal for both, unmeasured. |
| `P_sensor` | VL53L0X package protrusion: breakout board underside → optical face (`TOF_ORIGIN`) | **Resolved (Rev 7): `P_sensor_nominal = 1.0 mm`** — ST's published Optical LGA12 package height (package `4.4 × 2.4 × 1.0 mm`). Normal solder/assembly tolerance around this value is an enclosure/standoff tolerance question, not a PCB hold. |
| `G_top` | Air gap, `TOF_ORIGIN` → lid top (near) surface | **Design target**, achieved by the lid-facing standoff segment (§3.1). Target: 1.5 mm |
| `G_vent` | Equivalent gap for SHT31 | **Derived**, not independently targeted, once `G_top` fixes the shared lid plane (§3.1) |
| `H_lid` | Lid thickness | Free/parametric, independent material choice |
| `D_far = G_top + H_lid` | `TOF_ORIGIN` → lid chamber-side (far) surface | Derived — sizes the optical bore (§1.4). Does **not** depend on `H_conn`. |
| `L_total_J3 = H_conn + t_board + P_sensor + G_top` | Carrier PCB underside → lid top surface, at J3 | Derived: `11.05 + 1.3 + 1.0 + 1.5 = 14.85 mm` (illustrative — `t_board` is still an unmeasured enclosure-fit value; `H_conn` and `P_sensor` are now both resolved nominals; `G_top` is a design target) — see §3.1 |

### 3.1 Standoffs are two stacked segments per sensor, not one free length

**Plug-in module architecture.** Each sensor is a plug-in module: a Samtec
SSW female socket is soldered to the carrier PCB; the breakout module's
own male header pins plug into it. The female header and the mated male
pins fix the board's Z position once seated — a standoff cannot
independently choose a different height while the connector "just
tolerates" it. The fix, carried over from Rev 2, is two stacked standoff
segments per sensor on the same M2.5 screw path already used for the
two-hole rigid retention, with the sensor board sandwiched between them
(for J4, as of Rev 7, this describes the lid pocket-clip's tabs, not a
standoff/screw — same Z-constraint, different hardware, §2.3):

- **Standoff A** (carrier PCB underside → breakout board top surface):
  nominal length `Standoff_A_nominal = H_conn = 11.05 mm`. The connector
  establishes the seated Z position; the mechanical support meets the
  breakout at that same plane, with no built-in offset. An
  intentionally-undersized rigid standoff was considered and rejected
  (Rev 5) — on a rigid M2.5-screw clamp, cutting the standoff deliberately
  shorter than `H_conn` doesn't create a working tolerance mechanism, it
  just forces the screw to close that gap by flexing a PCB, preloading the
  connector's own pins, or leaving the stack not actually clamped. **Real
  tolerance accommodation is a separate, still-open decision** — resolving
  `H_conn` doesn't resolve this too — once real parts are in hand, options
  worth considering include a spacer machined to a tighter matched
  tolerance, a compliant washer that absorbs small stack-up variation
  without applying continuous Z preload to the header pins, shoulder-style
  retention, or a clip that constrains rocking without clamping the boards
  rigidly together along Z. None of these is selected here — this is an
  **enclosure/mechanical fit-check item (Rev 7 reclassification)**, not a
  PCB fabrication hold (see the closing list below).
- **Standoff B** (breakout board underside → lid top surface): length
  `P_sensor + G_top = 2.5 mm`. ONE physical spacer spanning from the
  board's underside to the lid; `TOF_ORIGIN` sits partway along that run,
  `P_sensor` below the board. This segment never depended on `H_conn`.

**Connector: Samtec SSW selected, `H_conn_nominal = 11.05 mm`.** The
carrier-side socket is **Samtec `SSW-106-01-T-S`** (J3, 1×6) and
**`SSW-104-01-T-S`** (J4, 1×4) — 2.54 mm pitch, single-row, through-hole,
lead-free solderable (`-S` row option). The mating male pins are the loose
2.54 mm header strips already supplied with the ALAMSCN VL53L0X-V2 and
HiLetgo GY-SHT31-D breakouts — not a separately selected or premium
replacement part, per instruction, unless a real fit problem turns up.
`H_conn_nominal = 11.05 mm` is the resolved carrier-PCB-underside-to-
breakout-board-top distance for this selected SSW stack; it comes from the
connector-stack decision made outside this document, not re-derived here.

**Worked example — concrete, using the resolved `H_conn` and `P_sensor`.**
Known values: `H_conn = 11.05 mm` (resolved), `t_board = 1.3 mm`
(enclosure-fit, unmeasured), `P_sensor = 1.0 mm` (resolved nominal),
`G_top = 1.5 mm` (target). `H_lid` shown at 3 mm for illustration only —
still free/parametric.

```
Standoff A (nominal)   = H_conn                  = 11.05 mm
Standoff B              = P_sensor + G_top        = 2.5 mm
L_total_J3               = H_conn + t_board + P_sensor + G_top
                         = 11.05 + 1.3 + 1.0 + 1.5 = 14.85 mm
D_far (at H_lid=3 mm)   = G_top + H_lid            = 4.5 mm     (still no H_conn dependency)
```

```
                                          Z (mm, carrier PCB top = 0)
  ═══════════════════════════════   Z =   0.00       carrier PCB top
  ┃▓▓▓▓▓▓▓▓▓▓ carrier PCB ▓▓▓▓▓┃
  ═══════════════════════════════   Z =  −1.60        carrier PCB bottom (t_carrier)
       ┊ Standoff A (nominal)    ┊  Z =  −1.60 .. −12.65   support only —
       ┊ = H_conn = 11.05 mm     ┊              meets the breakout at the SAME
       ┊ (tolerance accommodation┊              plane the connector seats it at,
       ┊  left open — see text)  ┊              not an intentional undersize
  - - -│- - - - - - - - - - - - -│- - -  Z = −12.65        breakout board TOP
       │ VL53L0X breakout module,│       (fixed by the connector, once mated —
       │ plugged into socket,    │       H_conn = 11.05 mm, resolved)
       │ t_board = 1.3 mm        │  Z = −12.65 .. −13.95
  - - -│- - - - - - - - - - - - -│- - -  Z = −13.95        board UNDERSIDE
       ┊ Standoff B (free,       ┊  Z = −13.95 .. −16.45
       ┊  no H_conn dependency)  ┊              length = P_sensor+G_top = 2.5 mm
       ┊ = P_sensor + G_top      ┊
  · · ·│· · package (P_sensor) ·│· · ·  Z = −14.95        TOF_ORIGIN (optical
       │· · · · · G_top · · · · ·│               face) — inside the Standoff B
       │                         │               run, NOT at the board underside
  ┌────┴─────────────────────────┴────┐
  │              LID  (H_lid)          │  Z = −16.45 .. −19.45  (H_lid=3mm shown
  └────┬─────────────────────────┬────┘             for illustration — free param)
  ~ ~ ~│~ ~ ~ chamber interior ~~│~ ~ ~   Z < −19.45, proofing chamber
```

`D_far` (`TOF_ORIGIN` → lid far surface) = `−14.95 → −19.45 = 4.5 mm =
G_top + H_lid`, matching §1.4 exactly — confirms the bore-sizing math and
the now-concrete standoff math agree. This Z-stack is unaffected by J3's
Rev 7 XY rotation — that change only moved J3's mounting-hole/optical
position in the board plane, not any Z dimension.

**`t_board` is still an unmeasured enclosure-fit value — `H_conn` and
`P_sensor` are now both resolved nominals.** The Z numbers above are a
concrete worked example for the selected connector stack and Rev A
optical nominal, not a fully frozen enclosure design: `t_board` (real
breakout thickness) still needs physical measurement for a tight lid fit
(see the closing list), and `G_top` is a design target, not yet locked to
a specific lid. Separately, how real manufacturing tolerance on the
seated stack gets accommodated (a matched-tolerance spacer, a compliant
washer, shoulder-style retention, a rocking-only clip, or similar) is an
open mechanical-detail decision, not resolved by `H_conn_nominal` — it
isn't solved by adjusting Standoff A's nominal length. None of this holds
Gerber generation.

**Same lid plane serves both sensors.** The lid is one flat plate, so
whatever sets `L_total_J3` applies to the whole lid, including under J4.
J3 and J4 use the same Samtec SSW family (same `-01-T-S` lead style /
row option, differing only in pin count), so `H_conn` is the same
resolved 11.05 mm for both. Assuming both breakout boards share the same
provisional `t_board`:

```
G_vent = L_total_J3 − H_conn_J4 − t_board_J4
       = 14.85 − 11.05 − 1.3
       = 2.5 mm
```

— larger than the earlier informal 0.5-1 mm target, because the shared
lid plane is set relative to the VL53L0X's optical face, one `P_sensor`
further from the board than the SHT31 side. Still workable for a sensor
with no FOV requirement. If SHT31's real board thickness turns out to
differ from J3's once both are physically measured, `G_vent` would need
to be recomputed directly rather than assumed equal.

### 3.2 Cutouts required in the lid

1. **VL53L0X optical bore**: **Ø3.0 mm** (at `H_lid` = 3 mm; recompute via
   §1.4's formula for a different lid thickness), centered exactly on
   `LID_ORIGIN` — which, as of Rev 7, *is* `TOF_ORIGIN` by construction
   (§1.3), so no offset-centering or oversizing is needed anymore.
   Straight through the full lid thickness, axis normal to the lid.
2. **VL53L0X standoff clearance**: two Ø3.2-4 mm clearance holes at
   **`(-10, -2.2)` and `(+10, -2.2)`** — `J3_MOUNT_ORIGIN`-referenced,
   moved by Rev 7's J3 rotation (previously `(-10, 0)`/`(+10, 0)`) — each
   carrying a stacked Standoff A + Standoff B pair per §3.1. Standoff A =
   `H_conn_nominal` = 11.05 mm (resolved); Standoff B = 2.5 mm. The
   tolerance-accommodation method for Standoff A is an open
   enclosure-fit item (§3.1), not a PCB hold.
3. **SHT31 vent pocket**: rectangular recess sized to ~11.2 x 13.6 mm
   (board outline + 0.5 mm/side clearance), under J4's real board
   position, with the 6-8x Ø1.5 mm vent pattern from 2.2.
4. **SHT31 retention tabs/ribs**: lid-molded pocket-clip features per
   §2.3 (Rev 7), positioned at `H_conn`'s mated height, same constraint a
   standoff would have had. No carrier PCB feature required — this is a
   lid-CAD item only.

The cutout *positions* don't depend on `H_lid` or `H_conn`, except that
cutout 2's exact XY moved with Rev 7's J3 rotation (a one-time PCB-driven
update, already reflected above). The VL53L0X bore *diameter* depends on
`H_lid` (via `D_far`), not on `H_conn`. The standoff *lengths* (§3.1)
depend on `H_lid` (via `L_total_J3`) and, for Standoff A, on the resolved
`H_conn_nominal = 11.05 mm`.

## Remaining fabrication holds

**None.** As of Rev 7, nothing blocks Gerber generation for this PCB — the
VL53L0X optical XY alignment, the SHT31 retention approach, `P_sensor`,
and the connector stack (`H_conn`, socket selection) are all resolved.

### Enclosure / mechanical fit-check items (not PCB holds)

Left open deliberately — none of these require a PCB change, and none
block fabrication, but the lid/enclosure design (not yet started) will
eventually want them resolved:

1. **Breakout PCB thickness** (`t_board`, both J3 and J4, §3.0) —
   currently a generic 1.3 mm small-FR4-board assumption for both,
   unmeasured. Affects lid/standoff fit only.
2. **Final tolerance-accommodation method for Standoff A** (§3.1) — a
   nominal target length (`H_conn_nominal = 11.05 mm`) exists, but how
   real assembly tolerance on that seated stack gets accommodated
   (matched-tolerance spacer, compliant washer, shoulder-style retention,
   rocking-only clip, or similar) is still an open mechanical-detail
   decision, and applies to J4's pocket-clip tabs too (§2.3).
3. **SHT31 pocket-clip tab/rib geometry** (§2.3) — the retention approach
   is decided; the exact tab dimensions are a lid-CAD detail, not started.
4. *(Nice-to-have, not blocking):* physical caliper/microscope
   confirmation of the 2.2 mm `TOF_ORIGIN` nominal (§1.2) and the 1.0 mm
   `P_sensor` nominal (§3.0) against the exact ALAMSCN part, useful for
   optimizing a future tighter lid opening — but the current Ø3.0 mm bore
   already carries a 1.0 mm total alignment margin (§1.4), so a modest
   discrepancy from these nominals doesn't create a hard failure, only a
   less-than-maximally-tight opening.

## References

- ST VL53L0X datasheet (DocID029104 Rev 2), Section 1.1 (package: Optical
  LGA12, 4.40 x 2.40 x 1.00 mm), Section 6 (outline drawing), FOV = 25°.
- ALAMSCN black VL53L0X-V2 listing (ASIN B0DGL2P6XC) product photography —
  source of the measured 1.2 offset; corroborated by an independent direct
  measurement of a common GY-VL53L0XV2 board (Rev 7).
- HiLetgo GY-SHT31-D product listing (ASIN B07ZSZW92J).
- ELEGOO EL-SM-012 product listing (ASIN B0D8T53CQ5).
- Samtec SSW/SSQ series mechanical drawing (Revision B, Nov 2018;
  `suddendocs.samtec.com/catalog_english/ssw_th.pdf`) — 2.54 mm pitch,
  single-row THT, 0.025" sq. post, insertion depth 3.68-6.35 mm, body
  length formula `2.54mm x N + 0.51mm`. Selected carrier parts: J1+J2 2x
  `SSW-115-01-T-S` (1×15, the two ESP32 socket rows), J3 `SSW-106-01-T-S`
  (1×6), J4 `SSW-104-01-T-S` (1×4). Supersedes the Rev 4/5 Samtec CES
  consideration.
- Footprints: `RevA_Sensors.pretty/ESP32_EL_SM_012_MODULE_OUTLINE.kicad_mod`
  (U1: mechanical-only, non-BOM — the ESP32 module itself, zero pads;
  split off the former combined `ESP32_EL_SM_012_CARRIER_2x15` footprint
  in the follow-on BOM-model cleanup),
  `RevA_Sensors.pretty/SSW-115-01-T-S_1x15.kicad_mod` (J1/J2, the two
  carrier-side ESP32 sockets — new, at the split-off footprint's former
  pad coordinates),
  `RevA_Sensors.pretty/VL53L0X_V2_1x06_2H_PRELIM.kicad_mod` (J3 —
  repositioned/rotated in Rev 7, pads/geometry otherwise unchanged),
  `RevA_Sensors.pretty/SHT31_GY-SHT31-D_1x04_PRELIM.kicad_mod` (J4 —
  retention-hole annotation removed in Rev 7, pads/geometry otherwise
  unchanged) — J3 and J4 checked against the Samtec SSW/SSQ drawing above
  and reused unmodified (Rev 6).

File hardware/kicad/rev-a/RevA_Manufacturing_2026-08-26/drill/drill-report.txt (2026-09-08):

Drill report for rev-a-carrier.kicad_pcb
Created on 2026-08-27T06:31:13

Copper Layer Stackup:
    =============================================================
    L1 :  F.Cu                      front
    L2 :  B.Cu                      back

Drill file 'rev-a-carrier-PTH.drl' contains
    plated through holes:
    =============================================================
    T1  0.300mm  0.0118"  (15 holes))
    T2  1.000mm  0.0394"  (40 holes))

    Total plated holes count 55

Drill file 'rev-a-carrier-NPTH.drl' contains
    unplated through holes:
    =============================================================
    T1  3.200mm  0.1260"  (5 holes))

    Total unplated holes count 5

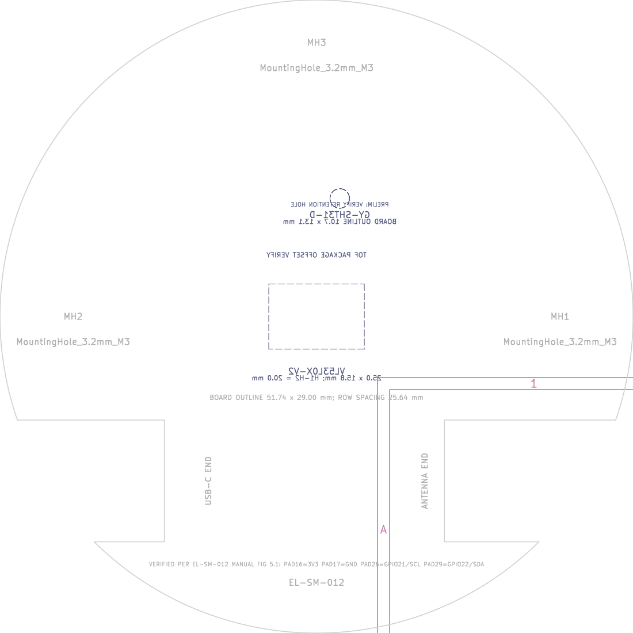
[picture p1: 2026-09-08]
hardware/kicad/rev-a/previews/mechanical.svg.png

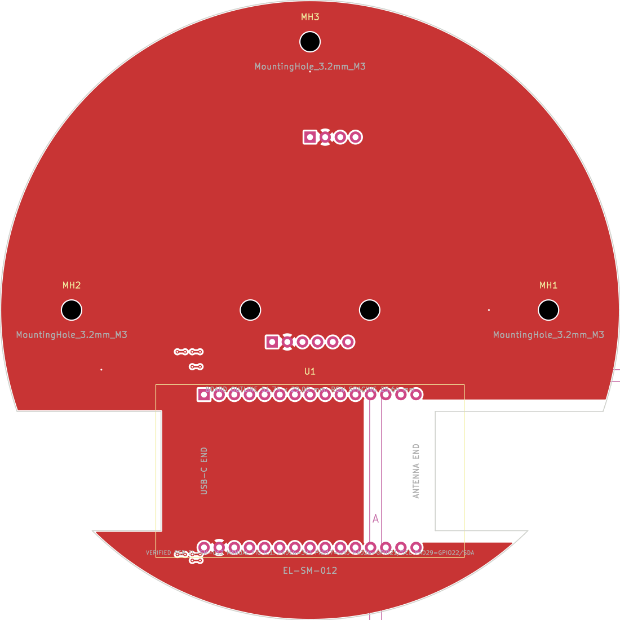
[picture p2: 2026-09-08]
hardware/kicad/rev-a/previews/top.svg.png

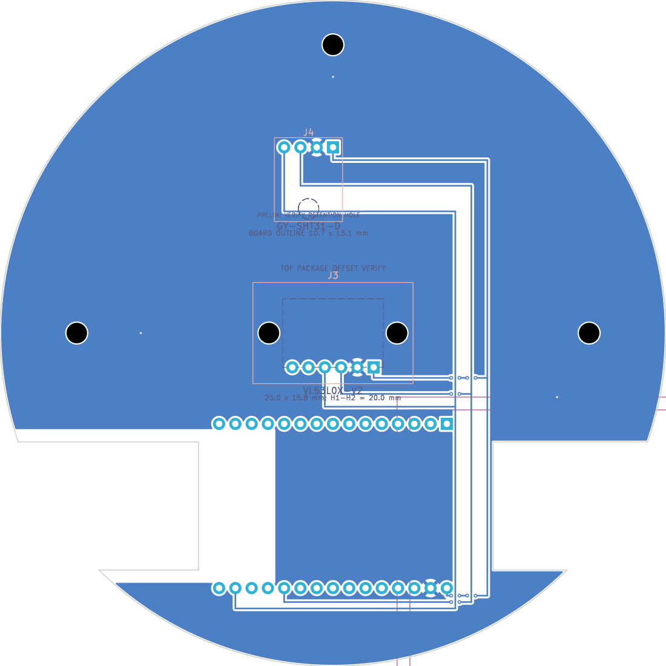
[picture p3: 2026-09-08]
hardware/kicad/rev-a/previews/bottom.svg.png

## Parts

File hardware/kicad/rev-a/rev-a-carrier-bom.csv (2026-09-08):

Refs | Value | Manufacturer | MPN | Footprint | Qty | DNP
J1,J2 | SSW-115-01-T-S | Samtec | SSW-115-01-T-S | RevA_Sensors:SSW-115-01-T-S_1x15 | 2
J3 | SSW-106-01-T-S | Samtec | SSW-106-01-T-S | RevA_Sensors:VL53L0X_V2_1x06_2H_PRELIM | 1
J4 | SSW-104-01-T-S | Samtec | SSW-104-01-T-S | RevA_Sensors:SHT31_GY-SHT31-D_1x04_PRELIM | 1

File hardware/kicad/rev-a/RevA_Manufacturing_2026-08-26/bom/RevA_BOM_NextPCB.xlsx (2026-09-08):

S/N | Designator | Quantity | Manufacturer Part Number | Procurement Type | Customer Note
1 | J1,J2 | 2 | SSW-115-01-T-S |  | Samtec; 1x15 THT socket
2 | J3 | 1 | SSW-106-01-T-S |  | Samtec; 1x6 THT socket
3 | J4 | 1 | SSW-104-01-T-S |  | Samtec; 1x4 THT socket

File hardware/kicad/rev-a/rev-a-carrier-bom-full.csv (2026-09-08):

Refs | Value | Manufacturer | MPN | Footprint | Qty | DNP | ExclBOM
J1 | SSW-115-01-T-S | Samtec | SSW-115-01-T-S | RevA_Sensors:SSW-115-01-T-S_1x15 | 1
J2 | SSW-115-01-T-S | Samtec | SSW-115-01-T-S | RevA_Sensors:SSW-115-01-T-S_1x15 | 1
J3 | SSW-106-01-T-S | Samtec | SSW-106-01-T-S | RevA_Sensors:VL53L0X_V2_1x06_2H_PRELIM | 1
J4 | SSW-104-01-T-S | Samtec | SSW-104-01-T-S | RevA_Sensors:SHT31_GY-SHT31-D_1x04_PRELIM | 1

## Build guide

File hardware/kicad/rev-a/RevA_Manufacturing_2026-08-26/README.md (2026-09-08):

# Bread Proof Monitor — Rev A Manufacturing Package

Generated 2026-08-26, revised 2026-08-27 (DFA fix + silkscreen-width
correction, see below) from
`rev-a-carrier.kicad_pcb` / `rev-a-carrier.kicad_sch`.
ERC: 0 errors, 0 warnings. DRC: 0 errors, 1 accepted cosmetic warning (see
`../README.md` "Exclusions"). Board: Ø104 mm, 2-layer, conventional
prototype design rules (0.25 mm trace / 0.20 mm clearance / 0.6 mm via,
0.3 mm drill). No relaxed tolerances.

## 2026-08-27 DFA fix — J3/J4 manufacturing silkscreen corrected

NextPCB's DFA review (report T-E110466AA1) flagged: *"The component is
vertical pin header while the silk in Gerber is for right-angle
component, is the part number correct?"* (J3, J4). The MPNs were always
correct (`SSW-106-01-T-S`, `SSW-104-01-T-S` — both straight/vertical THT
sockets); the problem was the **manufacturing silkscreen graphic**, not
the part number. J3/J4's silkscreen had been showing the outline of the
much larger *removable sensor breakout module* (the VL53L0X/SHT31 board
envelope — useful for enclosure/mechanical design, not for assembly) on
the same silkscreen layer as the real socket, with the actual 6-/4-pin
socket body floating inside it. NextPCB's assembly reviewer reasonably
read that large, oddly-placed outline as "the connector body" and it
didn't match a straight-pin part.

**Fix:** the module-envelope outlines moved to `Dwgs.User` (a
documentation/mechanical layer, not exported to manufacturing Gerbers),
each labeled `VL53L0X MODULE ENVELOPE` / `SHT31 MODULE ENVELOPE`. New,
correctly-sized silkscreen outlines were added on `B.Silkscreen` sized to
the actual Samtec SSW body-length formula (`2.54mm × N + 0.51mm`) for
length and Samtec's published single-row body width (2.41 mm / .095") for
width — 15.75 mm × 2.41 mm for J3 (`SSW-106-01-T-S`), 10.67 mm × 2.41 mm
for J4 (`SSW-104-01-T-S`), centered on the real pin rows. (An initial pass
used an unverified 5.0 mm placeholder width, corrected 2026-08-27 to the
2.41 mm figure per Samtec's TH SSW drawing.) J4's silkscreen
reference-designator text was nudged 1.2 mm to stay clear of the new,
tighter outline (was overlapping it). No copper, mask, drill, board
outline, placement, or BOM content changed — verified by content-diff
against the prior approved package: only `B_Silkscreen.gbr` changed.

## What NextPCB assembles

Only the four carrier-side sockets below are populated by the assembly
house. **Nothing else is on this BOM** — the ESP32 module and both sensor
breakouts are user-installed after assembly (see next section).

| Designator | Qty | Manufacturer | MPN | Package |
| --- | ---: | --- | --- | --- |
| J1, J2 | 2 | Samtec | `SSW-115-01-T-S` | 1×15, 2.54 mm pitch, THT |
| J3 | 1 | Samtec | `SSW-106-01-T-S` | 1×6, 2.54 mm pitch, THT |
| J4 | 1 | Samtec | `SSW-104-01-T-S` | 1×4, 2.54 mm pitch, THT |

All four are the same Samtec SSW family: 2.54 mm pitch, single-row,
through-hole, lead-free solderable (`-S` row option). J1/J2 are
electrically and mechanically identical parts (same footprint, same MPN)
— they're the two socket rows the ELEGOO EL-SM-012 ESP32 module plugs
into; a BOM grouped by MPN correctly reports them as one line, qty 2, so
they can't be mistaken for a single socket.

See `bom/RevA_assembly_BOM.csv` for the machine-readable version and
`position/RevA_placement.csv` for X/Y/rotation (all four parts are
through-hole, so a pick-and-place file has limited value for this board —
included for completeness, but hand/wave-solder placement referencing the
silkscreen reference designators is the expected assembly method).

## What is NOT on this BOM — user-installed plug-in modules

These three modules are **not procured or soldered by NextPCB**. They are
purchased separately and plugged into the sockets above by the end user
after the carrier PCB is assembled:

| Plugs into | Exact part | Amazon ASIN |
| --- | --- | --- |
| J1 + J2 | ELEGOO EL-SM-012 (ESP32 dev module) | B0D8T53CQ5 |
| J3 | ALAMSCN black VL53L0X-V2 breakout | B0DGL2P6XC |
| J4 | HiLetgo GY-SHT31-D breakout | B07ZSZW92J |

Each module mates directly with the carrier's female SSW sockets using
its own male pins — not a separately selected or premium replacement
part in any case, but the two modules arrive different ways: the ALAMSCN
VL53L0X-V2 and HiLetgo GY-SHT31-D breakouts (J3, J4) ship with loose
2.54 mm male header strips that the user solders onto the breakout
before plugging it in; the ELEGOO EL-SM-012 (J1, J2) instead plugs in
directly using its own existing male pin rows, already fixed to the
module — nothing to solder there. U1 (silkscreen reference for the ESP32
module's outline) is a mechanical-only footprint with zero pads — it
exists purely
so the module's footprint is visible on the silkscreen/assembly drawing
for placement reference; it is explicitly marked `in_bom=no`, `dnp=yes`
and will not appear in any BOM export.

## Package contents

- `gerbers/` — RS-274X Gerbers: `F_Cu`, `B_Cu`, `F_Mask`, `B_Mask`,
  `F_Silkscreen`, `B_Silkscreen`, `Edge_Cuts`, plus the `.gbrjob` job file.
  No paste layers (this board has no SMD pads — every part is
  through-hole).
- `drill/` — Excellon drill files, PTH and NPTH generated separately:
  `rev-a-carrier-PTH.drl` (55 holes: 15× Ø0.3 mm signal/detour vias, 40×
  Ø1.0 mm component pads across J1/J2/J3/J4), `rev-a-carrier-NPTH.drl` (5
  holes: 3× Ø3.2 mm carrier mounting holes MH1-MH3, 2× Ø3.2 mm VL53L0X
  retention holes at J3). Drill maps (PDF) and a text report included for
  cross-check.
- `bom/RevA_assembly_BOM.csv` — final assembly BOM, grouped by MPN (see
  table above).
- `position/RevA_placement.csv` — placement/position file (X/Y/rotation,
  mm, both sides), DNP items excluded.
- `fab-drawing/RevA_fabrication_drawing.svg` — board outline, mounting
  hole positions, and top-side silkscreen/fab reference text, fitted to
  the board's own ~104×104 mm extent.
- `RevA_Gerbers_NextPCB.zip` — `gerbers/` + `drill/` zipped together,
  ready to upload as-is to NextPCB's quote/order tool.

## Design notes relevant to fabrication

- **2-layer board**, Ø104 mm circular outline with a USB-C access notch
  and an antenna overhang notch cut into the upper hemisphere (see
  `../README.md` "Board outline").
- **VL53L0X socket (J3) is rotated 180° and offset** from the board's
  `LID_ORIGIN` — this is intentional (Rev 7 optical-alignment fix, see
  `../mechanical-stackup.md` §1.3), not a placement error. Mounting holes
  at `(±10, -2.2)` mm relative to `LID_ORIGIN`.
- **No SHT31 retention hole on the carrier** — retention is provided by
  the lid/enclosure (pocket-clip), not a PCB feature. This is intentional.
- Minimum via-to-via hole spacing: 0.7 mm edge-to-edge, comfortably above
  NextPCB's published 0.20 mm same-net via-to-via hole clearance minimum.
- No controlled impedance, no blind/buried vias, no HDI features — this
  is a conventional 2-layer prototype board.

## Not included

Lid/enclosure CAD is not part of this package — it isn't designed yet.
Nothing in this PCB package depends on it; see `../mechanical-stackup.md`
for the parametric lid interface (optical bore, vent pocket, standoff
heights) the eventual lid will need to satisfy.

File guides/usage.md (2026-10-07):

# Using Bread Proof Monitor

[Back to the project](../README.md)

## Calibration and Starting a Proof

Apply a profile first. Calibrate with the sensor, container, and lid positioned exactly as they will be during monitoring:

1. With the container empty, press **Set Empty Setup**.
2. Add the dough, smooth the top, and replace the lid.
3. Let it settle, then press **Set Starting Dough Height**.

The monitor takes five valid distance samples for calibration and uses their median. If it cannot capture a reading, check the sensor and setup, then try again. Complete any preparation steps from the linked recipe before starting the monitored stage.

Changing to a different profile clears the active run and empty calibration, even when both recipes use the Bulk stage. Starting another proof with **Start New Proof** keeps the current profile, stage, target, and empty calibration. Set a fresh empty calibration yourself if the container or sensor position has changed.

## Reading the Dashboard

The dashboard refreshes every 15 seconds. Sensors are normally read about every two seconds, so phone alerts can arrive before the next dashboard refresh.

Rise is calculated from dough height relative to the calibrated container. For profiles with folds, displayed progress includes progress carried forward from earlier segments. It is a guide to the monitored process, not a direct measurement of dough volume.

Each distance reading is the median of five valid samples, followed by smoothing. A higher progress reading must pass an additional confirmation period before it becomes the retained peak used for fold and target decisions. That period is about 8 seconds for a deep dough and stretches up to about 90 seconds for a shallow one, because a few millimeters of sensor noise is a much larger share of a shallow dough's height.

The monitor also enforces a minimum time for each segment. At 75°F this is generally 20 minutes, or 10 minutes for Focaccia. With a working temperature sensor, it scales that time within an 8–40 minute range. The sensor measures **ambient** temperature; it isn't a probe inside the dough. Paused time is excluded.

For most sourdough profiles, the target and fold triggers also adjust for temperature. Warmer dough lowers them so it is caught before it overproofs, using a slow average of the ambient reading (roughly an hour) rather than every swing in the air. A cooler room never raises them above the recipe's own numbers. Folds scale the same way, so they stay at the same fraction of the way to the target. Yeast profiles aren't adjusted.

You may see **Confirming target reached** while the displayed percentage is already at the target. The monitor is waiting for its confirmation conditions. These checks help with noise; you should still judge the dough before finishing.

If the confirmed rise gains less than 2 points in 30 minutes, and no fold or target is close, the status reads **Rise has slowed** and suggests checking the dough. That can be normal in a cool room or an early slow phase. The message clears on its own once the rise picks up, and the monitor keeps tracking either way.

## Folds and Other Handling Steps

When the current step calls for a fold:

1. Press **Pause Monitoring** before removing the lid.
2. Perform the fold and replace the lid.
3. Press **Resume Monitoring** and wait for readings to settle.
4. Press **Complete Step** when it becomes available.

Completing a step captures a new baseline while carrying forward retained progress. A new segment timer starts for the next milestone.

Distance readings stop during a pause, and there is a six-second settling delay after resuming. Leaving the lid off while running can cause a false reading.

## Re-baselining

Use **Re-baseline After Lid Off** after an unscheduled check or repositioning. It captures a new segment baseline and keeps the retained progress. It also restarts the segment's minimum waiting period.

Pause before handling the lid, resume when it is back, and allow readings to settle before re-baselining. Re-baselining preserves previously retained progress; it does not undo a false peak already accepted while the lid was off.

## Finishing and Final Proof

At the target, check how the dough looks and feels. **Finish Proof** records the finished result and queues feedback for that stage.

For a Bulk profile with a monitored Final stage, finishing prepares Final proof with its learned target. Most such profiles clear the empty calibration because the shaped dough uses a different setup. Follow the dashboard prompts to calibrate and capture a new starting height.

For a profile without monitored Final proof, follow the linked recipe for the remaining rests, shaping, and baking. Finishing stops distance readings and freezes the result for that stage unless the monitor moves on to preparing Final.

## Outcome Feedback

Rate the dough as it was when the stage ended, rather than judging the finished bake. Oven temperature and bake time can change the result without saying anything about the proof target.

Feedback is tracked separately for each recipe and stage:

- Two consecutive **Underproofed** ratings add five percentage points.
- Two consecutive **Overproofed** ratings subtract five percentage points.
- **Just Right** resets the streak without changing the learned adjustment.
- Switching from under to over, or over to under, starts a new streak.
- Adjustments are limited to ±25 points from the shipped suggestion, with overall target limits.

There are two pending-feedback slots, allowing Bulk and Final from one batch to wait together. Answer them before accumulating more finished stages across subsequent batches.

Submitting a rating or resetting learning reloads the dashboard so the profile list is refreshed. Your active proof keeps its applied target. To use another suggested target, select the profile/stage and apply it.

## Saved Settings and Restarts

The device saves calibration, selected profile and stage, targets, fold state, notification state, and pending feedback. Learned adjustments are stored separately on the same device.

During a proof, elapsed time and progress are saved periodically, normally once a minute. A reboot resumes from saved state; powered-off time is not counted, and the most recent unsaved progress may be lost.

**Start New Proof** clears the active run, timers, fold progress, final result, and alert state. It keeps calibration, profile, stage, target, Wi-Fi, ntfy topic, and learning.

A full flash erase clears all device settings, including the generated ntfy topic. Reconnect through **ProofMonitor-Setup**, complete setup, and subscribe to the new topic.

## Troubleshooting

- **No setup network:** a monitor with working saved Wi-Fi joins that network instead. Check your router or try [proofmonitor.local](http://proofmonitor.local).
- **The setup network has no internet:** that is expected. Stay connected long enough to open [192.168.4.1](http://192.168.4.1) and save your home Wi-Fi details.
- **The dashboard address does not open:** use the device's LAN IP from your router. Serial logs also show the IP after connection.
- **Distance readings are stale or unstable:** check the sensor connections, optical path, and lid position. Fresh readings are needed for step completion and re-baselining.
- **Rise jumps after moving the lid:** pause before handling it. A close, rigid mount and a stable dough surface make readings easier to interpret.
- **No phone alert:** check the internet connection, topic subscription, and the dashboard's test notification action.

The **Calibration Test** profile is available in Advanced for sensor checks. It uses the normal confirmation and timing behavior.

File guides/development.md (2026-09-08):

# Building the Firmware

[Back to the project](../README.md)

Most users can use the browser installer. These instructions are for changing the firmware or packaging a new version.

## Arduino IDE

The sketch folder must be named `bread_proof_monitor`, matching `bread_proof_monitor.ino`. If you download a GitHub ZIP, rename the extracted folder before opening it.

1. Install the ESP32 board package by Espressif Systems.
2. Choose **ESP32 Dev Module**.
3. Choose **Huge APP (3MB No OTA/1MB SPIFFS)** under Partition Scheme. This is the layout used for the distributed firmware.
4. Install **Adafruit VL53L0X** and **Adafruit SHT31 Library**, including their dependencies.
5. Open `bread_proof_monitor.ino`, compile, then upload.

The current local build uses:

| Component | Version |
| --- | --- |
| Arduino ESP32 core | 3.3.10 |
| Adafruit VL53L0X | 1.2.5 |
| Adafruit SHT31 Library | 2.2.2 |
| Adafruit BusIO | 1.17.4 |

The firmware also uses WiFi, WebServer, ESPmDNS, Preferences, HTTPClient, and WiFiClientSecure from the ESP32 core. Keep **GPIO22 = SDA** and **GPIO21 = SCL**.

## Arduino CLI

From a checkout named `bread_proof_monitor`, with Arduino CLI and those dependencies installed:

```bash
arduino-cli compile --fqbn esp32:esp32:esp32:PartitionScheme=huge_app --build-path .arduino/build .
arduino-cli upload --fqbn esp32:esp32:esp32:PartitionScheme=huge_app --port YOUR_SERIAL_PORT --input-dir .arduino/build .
```

Replace `YOUR_SERIAL_PORT` with the port reported by `arduino-cli board list`.

On macOS or Linux with zsh, the existing convenience scripts are also available:

```bash
./tools/compile.sh
./tools/upload.sh
./tools/monitor.sh
```

Their defaults are the same Huge APP board configuration, `/dev/cu.usbserial-0001`, and 115200 baud. Override the port with `PORT=/dev/your-port ./tools/upload.sh` or the monitor speed with `MONITOR_BAUD=74880 ./tools/monitor.sh`.

## Prepare a Browser Installer Build

From the project root:

```bash
python3 tools/prepare_installer.py --version 0.1.0-preview
```

Use an explicit version each time you prepare a release. The script compiles the current source, validates the chip, image headers, partition layout, and flash regions, then writes the four firmware parts, manifest, build information, and checksums into `docs/firmware/`.

It requires Python 3 and the Arduino CLI environment described above. It does not upload to a board or publish anything. It stages the sketch under `.arduino/`, so packaging also works if the repository folder has a different name.

Check the distributed package and its protection against wrong-chip images, changed layouts, and writes over saved settings:

```bash
python3 -m unittest discover -s tools -p 'test_*.py'
```

The installer deliberately uses separate flash parts. Sending the padded 4 MB merged image would also overwrite the space containing device settings even when the user did not request an erase. The packaged parts avoid that settings region. Keep the current partition layout when offering an update that preserves settings.

Preview the installer with:

```bash
python3 -m http.server 8765 --bind 127.0.0.1 --directory docs
```

Open [http://localhost:8765](http://localhost:8765). Web Serial requires HTTPS when hosted; localhost is suitable for local development. The installer library is loaded from ESP Web Tools and needs internet access.

## Diagnostics

The dashboard polls `/data` every 15 seconds. Along with visible fields, that endpoint includes segment baseline, completed-progress offset, and retained peak values for inspecting the rise calculations. Use the device's LAN IP for repeated scripted reads if `.local` resolution is unreliable.

The serial monitor runs at 115200 baud and reports sensors, Wi-Fi connection details, proof state, and notification results. Keep device logs and flash dumps out of public releases: they may contain your Wi-Fi name or ntfy topic.

## Publishing

See [Publishing on GitHub](publishing.md) for the repository and GitHub Pages setup, release checks, and preparing future updates.

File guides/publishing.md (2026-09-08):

# Publishing on GitHub

[Back to the project](../README.md)

The repository contains the static installer and its matching firmware package. This guide covers publishing and maintaining them together.

## Project Addresses

- Repository: `Canterrain/bread-proof-monitor`
- Installer: `https://canterrain.github.io/bread-proof-monitor/`

When publishing a fork under another name, update the README and installer links. For source builds, clone into a folder named `bread_proof_monitor` or use the packaging script, which stages the sketch with that name.

## Release Checks

- Keep the README and installer links aligned with the repository name.
- Licensing follows the clock projects: CC BY-NC 4.0, © 2026 Josh Hendrickson.
- Run a USB browser installation on the intended ESP32, check both sensors, complete Wi-Fi setup, and verify an alert.
- Check an update with Erase device unchecked retains settings, and a fresh erased install starts setup correctly.

The local firmware build and package validation are useful checks, but they do not establish that USB installation has been tested on hardware.

## Repository Contents

Publish the firmware sources, tools, README, guides, `docs/` installer, and intended hardware files. The `.gitignore` excludes local build products, OS metadata, editor backups, and KiCad session/backup files. The intentional firmware under `docs/firmware/` is included.

Use the compiled release files, never a dump read from a personal device. The hardware directory includes design history alongside the finalized Rev A files; start with `hardware/kicad/rev-a/README.md` for the current design.

## Enable GitHub Pages

After the repository and its reviewed files are on GitHub:

1. Open **Settings → Pages**.
2. Under Build and deployment, choose **Deploy from a branch**.
3. Select **main** and **/docs**, then save.
4. Wait for the Pages deployment to complete and open the address GitHub provides.
5. Confirm the install page, `firmware/manifest.json`, and all four `.bin` files are served, then test the installer over USB.

The site is static HTML, CSS, and JavaScript, matching the approach used by Round Weather Display. `docs/.nojekyll` keeps Jekyll processing out of the deployment. A separate website framework or hosting service is not needed.

See [GitHub's publishing-source instructions](https://docs.github.com/en/pages/getting-started-with-github-pages/configuring-a-publishing-source-for-your-github-pages-site).

## Publish an Update

1. Prepare firmware with an explicit new version: `python3 tools/prepare_installer.py --version YOUR_VERSION`.
2. Test the firmware on hardware and inspect `docs/firmware/build-info.json` and `SHA256SUMS`.
3. Commit the source and its corresponding generated firmware together.
4. Push the reviewed change. Pages republishes the installer from `main` and `/docs`.

Do not package from a stale build directory. The preparation script always compiles first and refuses unexpected chip, partition, or flash-header settings. If a future version changes the partition layout, update the installer instructions to require an erase instead of promising saved-setting retention.

## Installer References

- [Round Weather Display installer source](https://github.com/Canterrain/round-weather-display/blob/main/docs/index.html)
- [ESP Web Tools documentation](https://esphome.github.io/esp-web-tools/)

Bread Proof Monitor uses its existing Wi-Fi access-point setup after installation. It does not implement Improv Serial provisioning, so the installer skips that optional step.

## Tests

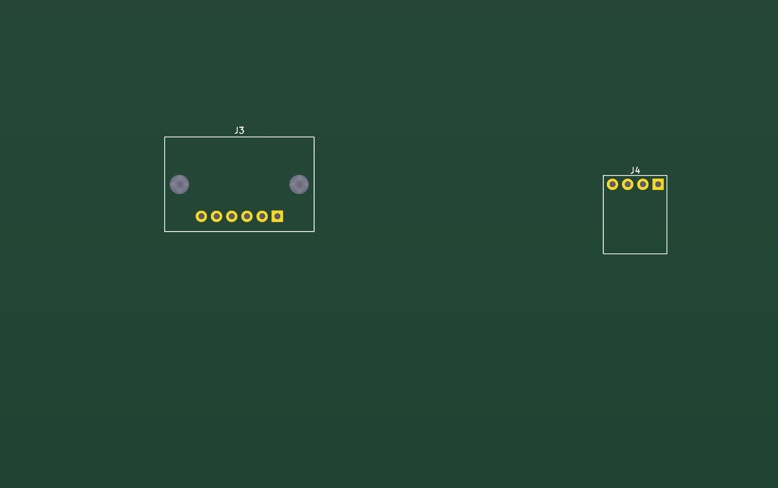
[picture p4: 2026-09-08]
hardware/kicad/validation-preview-bottom.png

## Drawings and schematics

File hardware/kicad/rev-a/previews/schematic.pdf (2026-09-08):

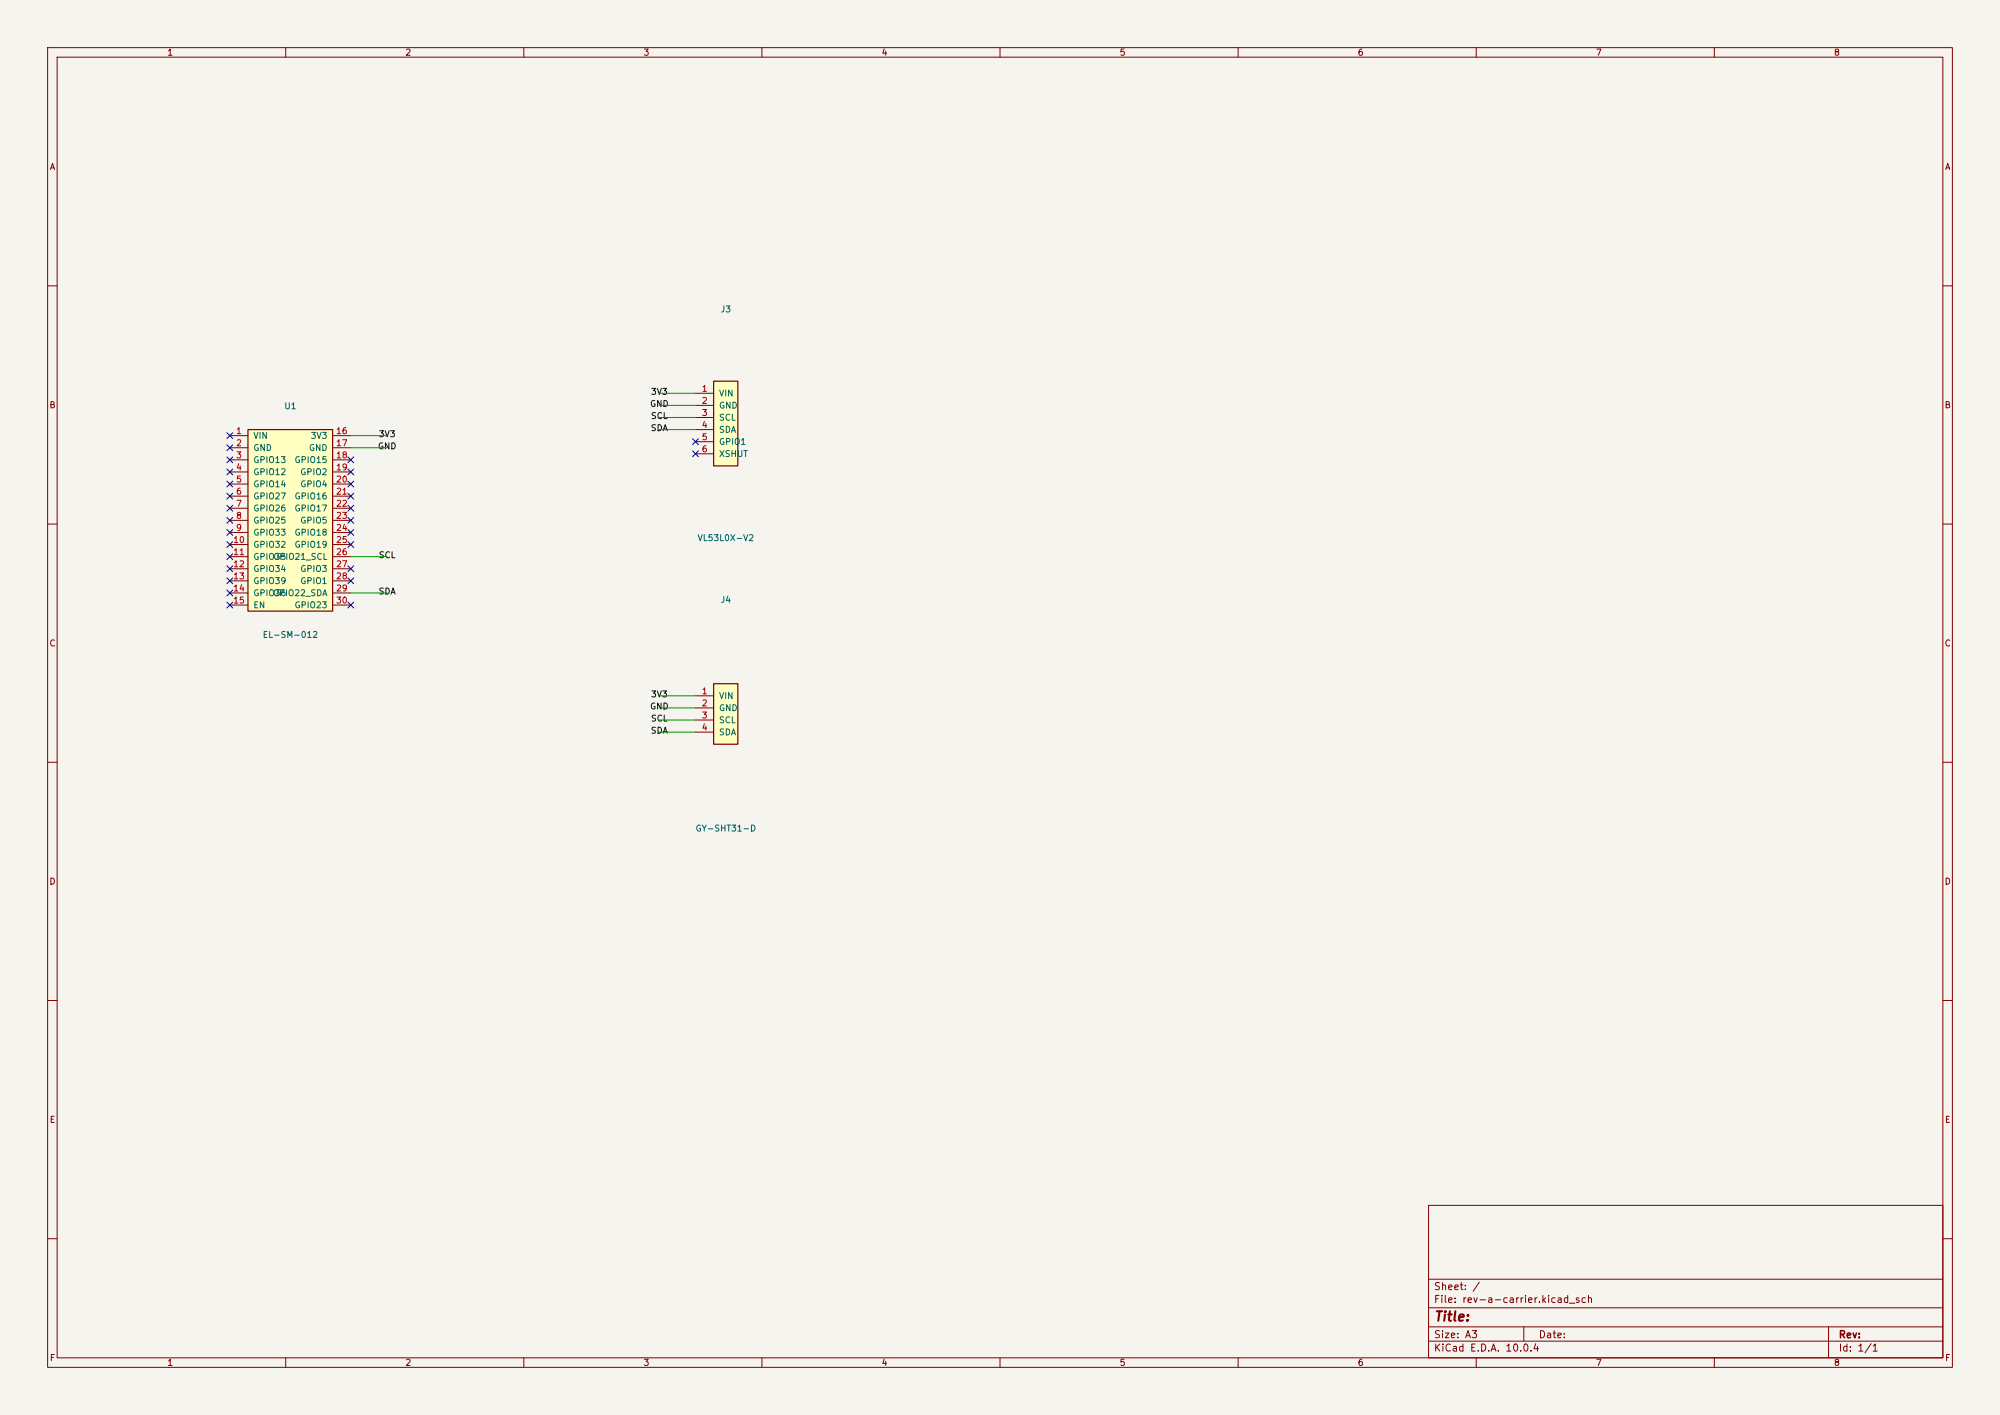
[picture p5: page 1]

Size: A3 | Rev:
KiCad E.D.A. 10.0.4 | Id: 1/1

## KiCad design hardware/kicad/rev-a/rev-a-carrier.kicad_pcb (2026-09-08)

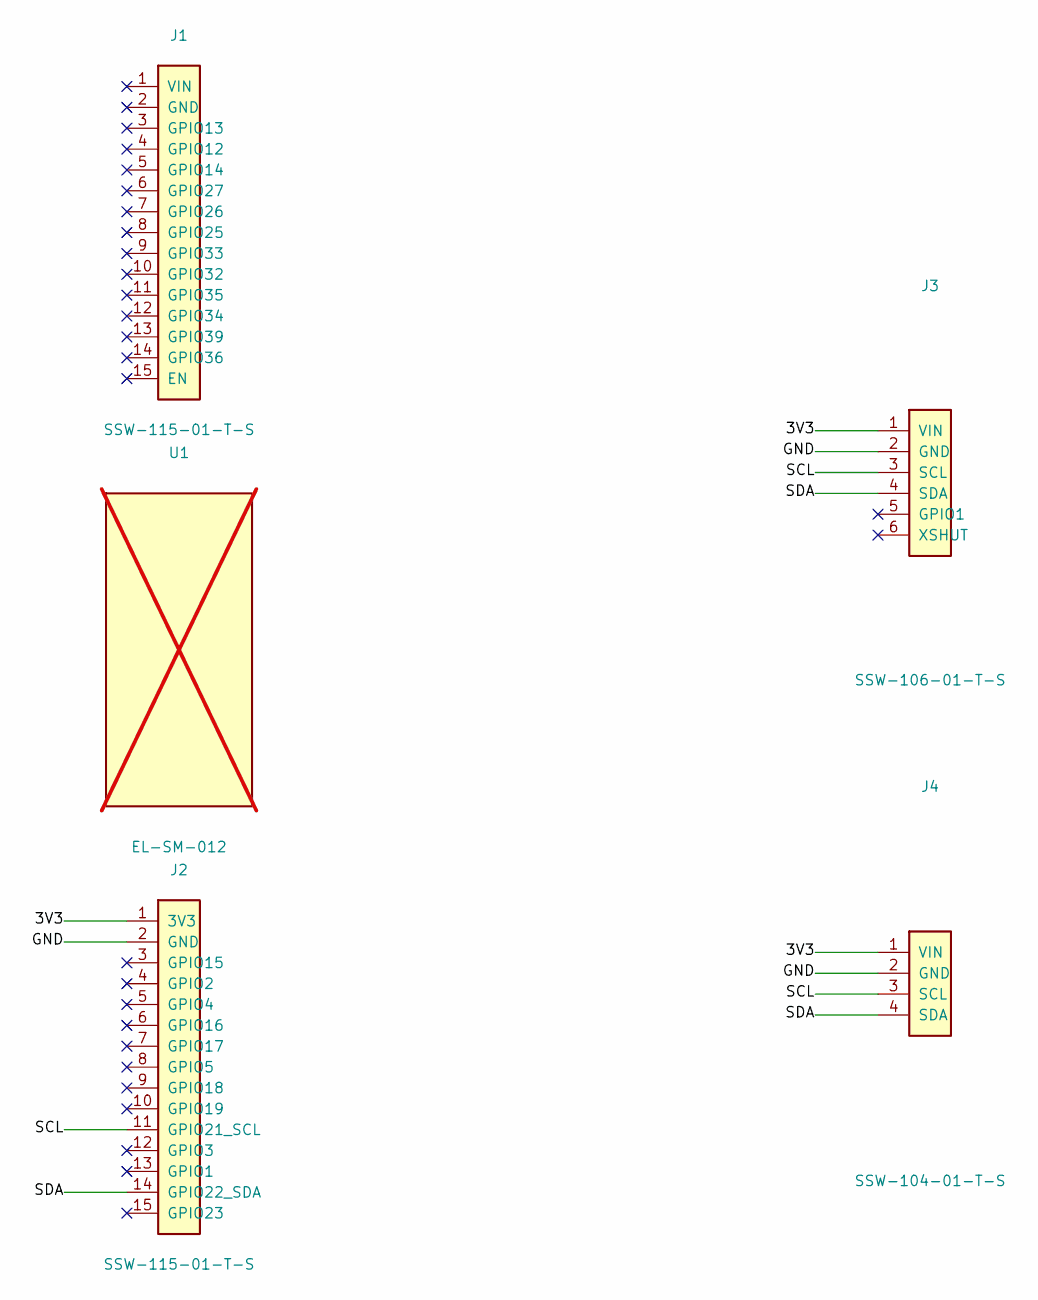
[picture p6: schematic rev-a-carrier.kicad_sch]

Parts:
J1, J2: SSW-115-01-T-S; SSW-115-01-T-S_1x15; MPN SSW-115-01-T-S
J3: SSW-106-01-T-S; VL53L0X_V2_1x06_2H_PRELIM; MPN SSW-106-01-T-S
J4: SSW-104-01-T-S; SHT31_GY-SHT31-D_1x04_PRELIM; MPN SSW-104-01-T-S
U1: EL-SM-012; ESP32_EL_SM_012_MODULE_OUTLINE; not fitted

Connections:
3V3: J2.1 (3V3), J3.1 (VIN), J4.1 (VIN)
GND: J2.2 (GND), J3.2 (GND), J4.2 (GND)
SCL: J2.11 (GPIO21_SCL), J3.3 (SCL), J4.3 (SCL)
SDA: J2.14 (GPIO22_SDA), J3.4 (SDA), J4.4 (SDA)

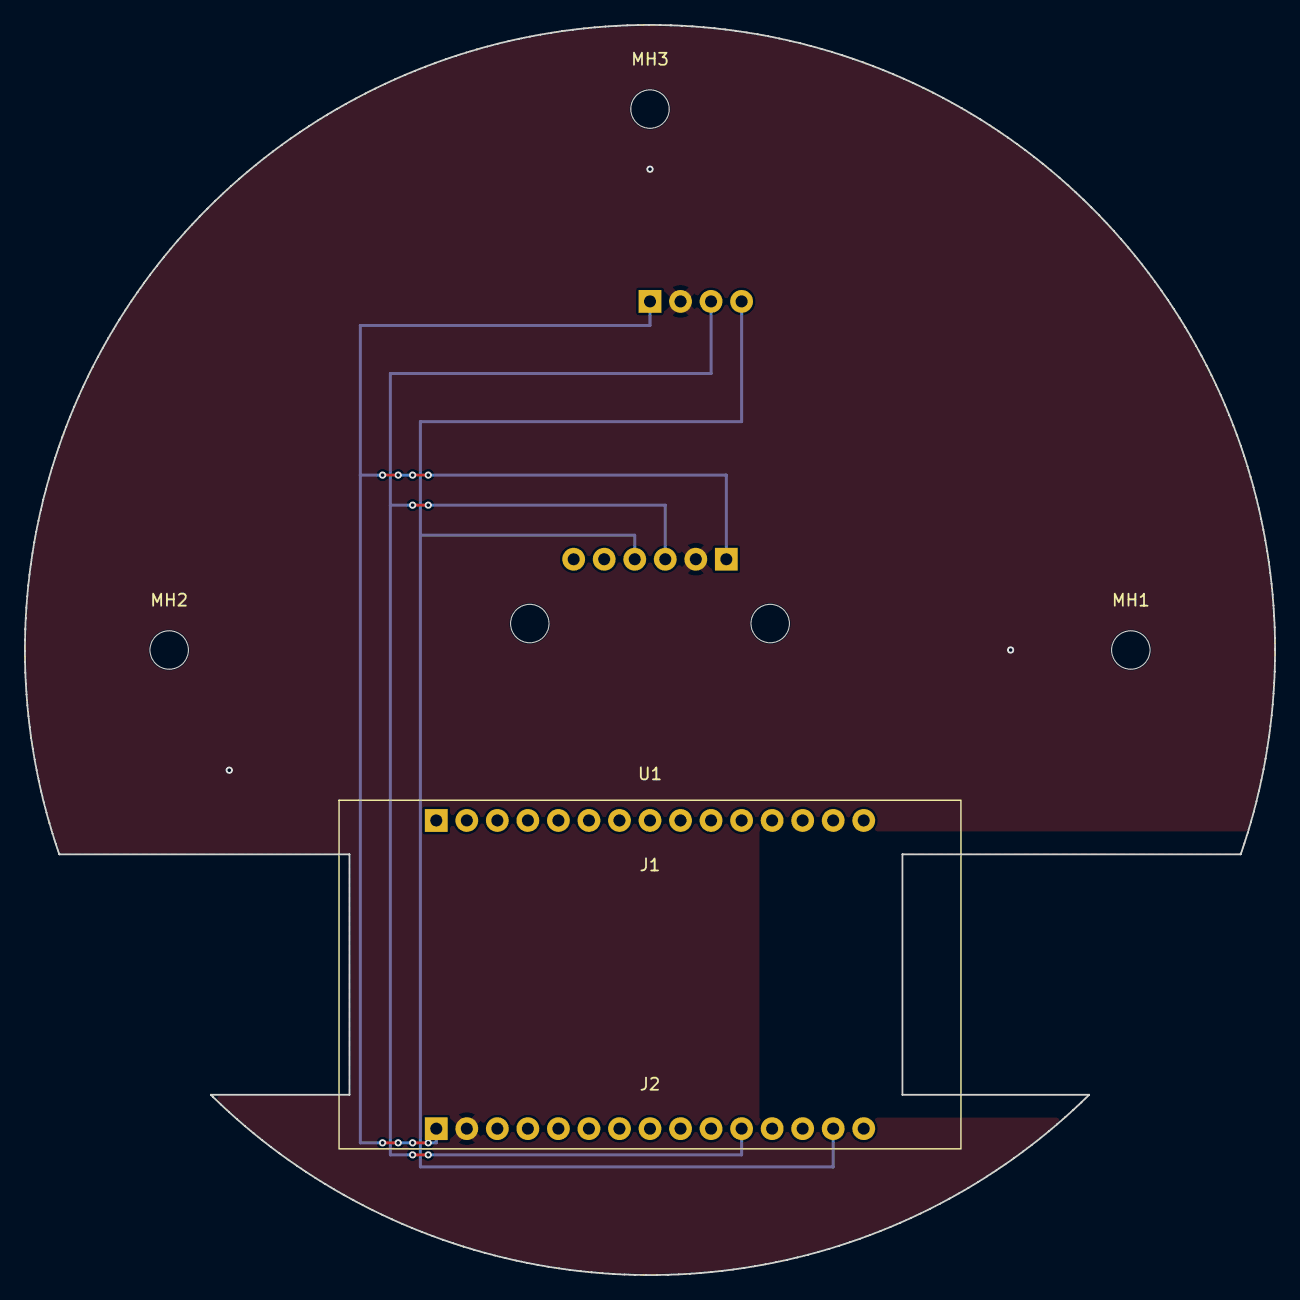
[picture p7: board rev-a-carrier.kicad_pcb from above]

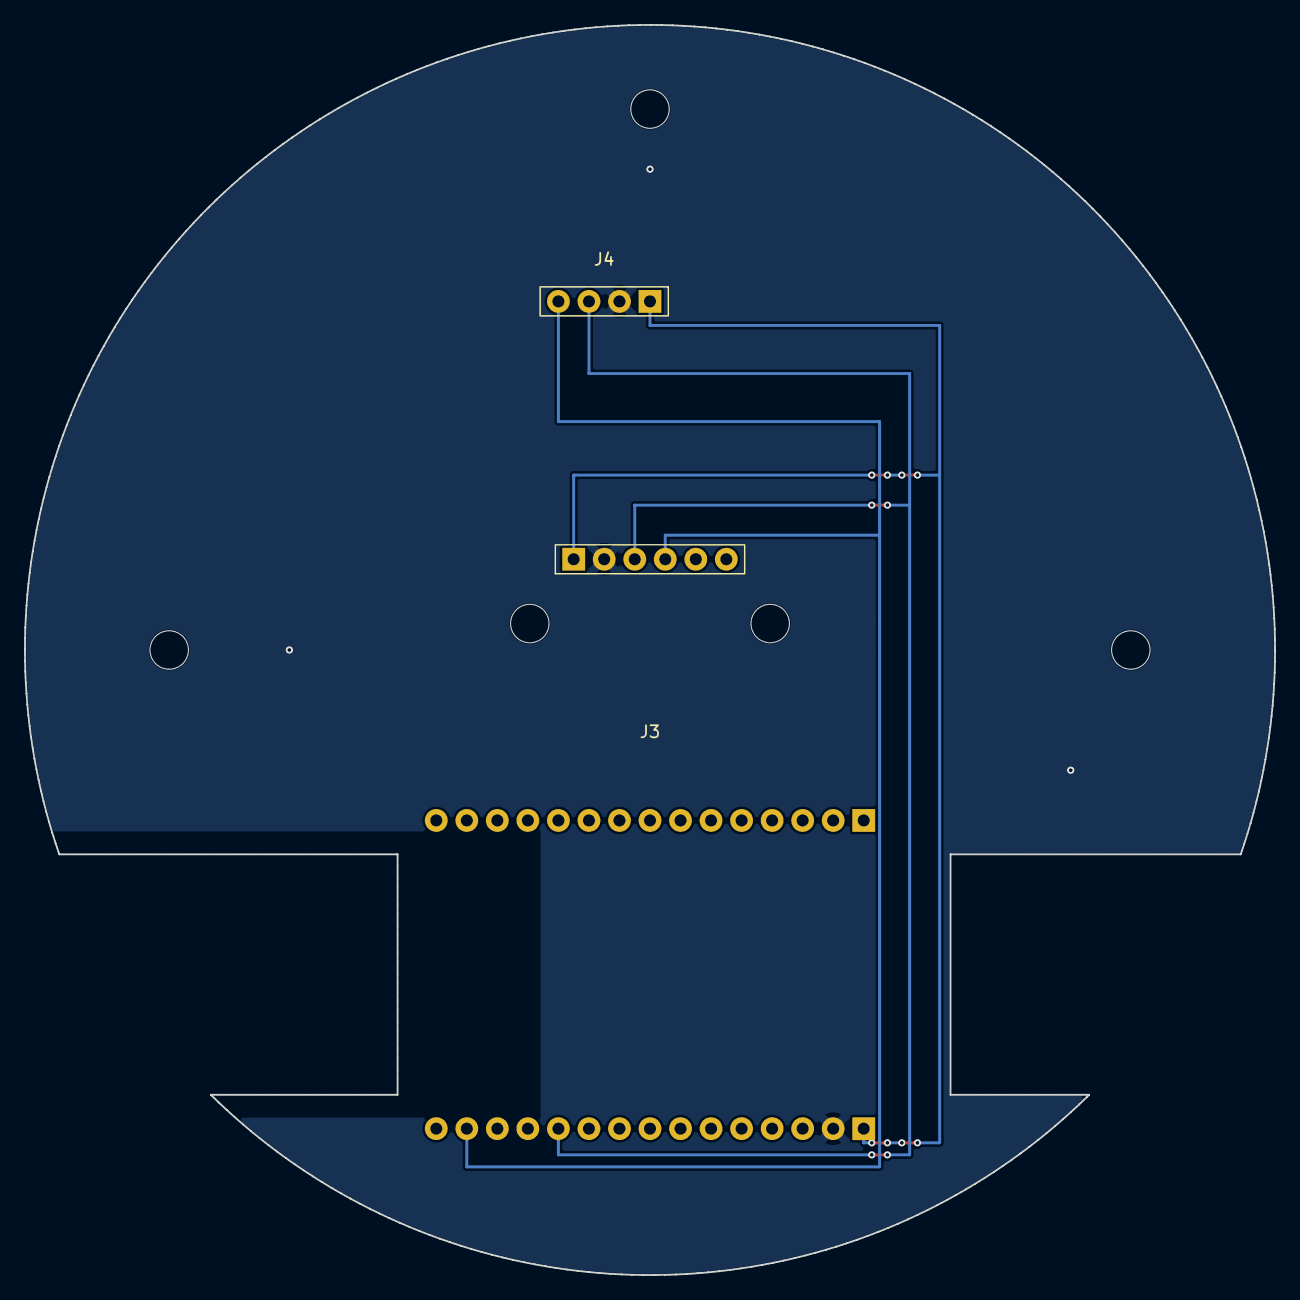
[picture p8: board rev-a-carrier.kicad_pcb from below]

Board: 2 copper layers, 104.0 x 104.0 mm, 8 parts (2 on the bottom side), 4 nets.

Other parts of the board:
MH1, MH2, MH3: MountingHole_3.2mm_M3

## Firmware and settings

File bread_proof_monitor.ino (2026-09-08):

#include <Preferences.h>
#include <WebServer.h>
#include <Wire.h>

#include "app_state.h"
#include "notifications.h"
#include "proof_state.h"
#include "sensor_reader.h"
#include "web_dashboard.h"
#include "wifi_setup.h"

WebServer server(80);
Preferences prefs;
AppState appState;

namespace {
void logReadings(const AppState& state) {
  Serial.print("Distance: ");
  Serial.print(state.smoothedDistanceMm);
  Serial.print(" mm | Rise: ");
  Serial.print(displayRisePercent(state));
  Serial.print("% | Target: ");
  Serial.print(state.targetRisePercent);
  Serial.print("% | Profile: ");
  Serial.print(state.selectedRecipe);
  Serial.print(" | Stage: ");
  Serial.print(state.selectedStage);
  Serial.print(" | Step: ");
  Serial.print(currentStepTitle(state));
  Serial.print(" | State: ");
  Serial.print(proofStateApiValue(state.proofState));
  Serial.print(" | Status: ");
  Serial.print(statusText(state));
  Serial.print(" | Temp: ");
  Serial.print(state.temperatureF);
  Serial.print(" F | Humidity: ");
  Serial.print(state.humidityPercent);
  Serial.println(" %");
}
}  // namespace

void setup() {
  Serial.begin(115200);
  delay(1000);

  Serial.println("Starting Proof Monitor...");

  // Preserve the existing clean wiring exactly: GPIO22 = SDA, GPIO21 = SCL.
  Wire.begin(SDA_PIN, SCL_PIN);

  prefs.begin("proof", false);
  loadAppState(prefs, appState);
  ensureNtfyTopic(prefs, appState);

  beginSensors(appState);

  Serial.println(appState.loxReady ? "VL53L0X found" : "VL53L0X NOT found");
  Serial.println(appState.shtReady ? "SHT31 found" : "SHT31 NOT found");

  readSensors(appState);

  const bool wifiConnected = connectHomeWifi(appState);
  if (!wifiConnected) startSetupMode(appState);

  configureWebServer(server, prefs, appState);
  server.begin();

  Serial.println("Web server started.");
}

void loop() {
  server.handleClient();

  if (appState.restartRequested && millis() >= appState.restartAt) {
    ESP.restart();
  }

  if (millis() - appState.lastSensorRead < 2000) return;

  appState.lastSensorRead = millis();

  const ProofState previousState = appState.proofState;
  const bool previousPendingEventActive = appState.pendingEventActive;
  const bool previousPendingEventNotified = appState.pendingEventNotified;
  readSensors(appState);

  if (appState.proofState != previousState ||
      appState.pendingEventActive != previousPendingEventActive ||
      appState.pendingEventNotified != previousPendingEventNotified) {
    saveAppState(prefs, appState);
    appState.lastProgressSaveMillis = millis();
  }

  checkTargetNotification(prefs, appState);
  maybeSaveProgress(prefs, appState);
  logReadings(appState);
}

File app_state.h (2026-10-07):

#pragma once

#include <Arduino.h>
#include <Preferences.h>

constexpr uint8_t SDA_PIN = 22;
constexpr uint8_t SCL_PIN = 21;

constexpr char SETUP_AP_NAME[] = "ProofMonitor-Setup";
constexpr char SETUP_AP_PASSWORD[] = "sourdough";
constexpr char MDNS_NAME[] = "proofmonitor";
constexpr char NTFY_BASE_URL[] = "https://ntfy.sh/";

enum class ProofState : uint8_t {
  NotStarted,
  Running,
  Paused,
  TargetReached,
  Finished
};

struct AppState {
  bool loxReady = false;
  bool shtReady = false;
  bool setupMode = false;
  bool targetNotified = false;
  bool recipeConfigured = false;
  // True for the first few minutes after Set Starting Dough Height or a completed fold, while
  // the dough relaxes back up. Rise is held steady until it ends - see proof_state.cpp.
  bool settlingActive = false;
  // True when the current settle window is a brief post-disturbance one (fold or manual
  // re-baseline, kPostDisturbanceSettleSeconds) rather than the longer initial-start one
  // (kSettleWindowSeconds) - see updateProofStateFromRise() in proof_state.cpp.
  bool settlingIsPostDisturbance = false;
  bool awaitingFinalProofStart = false;
  bool pendingEventActive = false;
  bool pendingEventNotified = false;
  bool outcomeFeedbackPending = false;
  // A second outcome can already be waiting when the first hasn't been rated yet - e.g. Bulk
  // finishes (queuing a Bulk rating) and then Final finishes too before the Bulk rating was
  // answered. Held here and promoted into the fields above once the current one is rated,
  // rather than overwriting it and losing that feedback.
  bool outcomeFeedbackPendingNext = false;

  String wifiSsid = "";
  String wifiPassword = "";
  String ntfyTopic = "";
  String selectedRecipe = "Custom";
  String selectedStage = "Bulk";
  String outcomeRecipe = "";
  String outcomeStage = "";
  String outcomeRecipeNext = "";
  String outcomeStageNext = "";

  int8_t pendingEventIndex = -1;
  uint8_t completedEventCount = 0;

  float emptyDistanceMm = 0.0f;
  float startDistanceMm = 0.0f;
  float segmentBaselineDistanceMm = 0.0f;
  float completedProgressOffsetPercent = 0.0f;
  float peakProgressPercent = 0.0f;
  float targetRisePercent = 75.0f;
  float smoothedDistanceMm = 0.0f;
  // The fresh median-of-5 reading from the most recent tick, before it's blended into
  // smoothedDistanceMm. Used only for peak-candidate confirmation, so a single bad tick can't
  // get smeared across many seconds of EMA smoothing and accidentally outlast the confirm
  // window - see updateProofStateFromRise() in proof_state.cpp.
  float lastRawDistanceMm = 0.0f;
  float temperatureF = 0.0f;
  // A slow-moving copy of temperatureF (roughly an hour's time constant) used to scale targets,
  // fold triggers, and the segment time floor. The sensor reads air in a lidded container, which
  // swings much faster than the dough's own temperature, so scaling off the raw reading made the
  // goalposts chase small air changes - see sensor_reader.cpp.
  float scalingTemperatureF = 0.0f;
  float humidityPercent = 0.0f;
  // Reference point for the "rise has slowed" message: the confirmed peak and when it was last
  // set. Moves up whenever the peak gains kStallMinGainPercent. Not persisted - a reboot just
  // restarts the window.
  float stallRefPeakPercent = 0.0f;
  unsigned long stallRefMillis = 0;
  float finalRisePercent = 0.0f;

  ProofState proofState = ProofState::NotStarted;

  unsigned long proofStartedAtMillis = 0;
  unsigned long elapsedOffsetSeconds = 0;
  unsigned long finalElapsedSeconds = 0;
  unsigned long segmentStartedAtMillis = 0;
  unsigned long segmentElapsedOffsetSeconds = 0;
  unsigned long resumeIgnoreUntil = 0;
  unsigned long peakCandidateSinceMillis = 0;
  unsigned long lastSensorRead = 0;
  unsigned long lastValidDistanceAtMillis = 0;
  unsigned long lastProgressSaveMillis = 0;

  bool restartRequested = false;
  unsigned long restartAt = 0;
};

ProofState parseProofState(const String& value);
String proofStateStorageValue(ProofState state);

void loadAppState(Preferences& prefs, AppState& state);
void saveAppState(Preferences& prefs, const AppState& state);
void maybeSaveProgress(Preferences& prefs, AppState& state, unsigned long intervalMs = 60000);
void scheduleRestart(AppState& state, unsigned long delayMs = 1000);

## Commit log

2026-09-08 Initial commit: Bread Proof Monitor firmware, hardware, and docs
    ESP32-based dough proof monitor with VL53L0X distance sensing, SHT31
    temperature/humidity, a local web dashboard, King Arthur recipe-based
    proof profiles with fold tracking, on-device outcome-based learning,
    ntfy phone alerts, and a browser-based USB installer via ESP Web Tools.
    Includes the Rev A carrier PCB design (KiCad source plus the finalized
    manufacturing package) as an optional alternative to hand-wiring, along
    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
    [RevA_BOM_NextPCB.xlsx, RevA_assembly_BOM.csv, RevA_placement.csv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]
2026-09-09 Add Sourdough Focaccia profile, fix Final-proof visual check wording
    - Add a Sourdough Focaccia preset next to the regular Focaccia entry,
    based on King Arthur's sourdough focaccia recipe: a single fold at
    the halfway point of a short 2-hour bulk rise, then an untracked
    overnight refrigerated rise before baking (no monitored Final stage).
    - Fix the "check for jiggle/poke/bubbles" doneness tip: "bubbles along
    the side" is a bulk-fermentation-in-a-container cue that doesn't
    apply to Final proof, which is almost always shaped dough in a pan,
    tray, or sheet. Final now gets its own wording ("a visibly puffy,
    rounded top") instead of reusing the Bulk-specific phrasing.
    - Regenerate t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
2026-09-19 Show ntfy alert topic on main dashboard, fix clipboard copy over HTTP
    Adds a 'Phone Alerts' section to the dashboard (between Details and
    Advanced) showing the ntfy topic, a copy button, subscribe instructions,
    and a Generate New Alert Topic button, so the topic is reachable without
    going through a Wi-Fi reset back to the setup page.
    Also fixes copyTopic() on both the dashboard and the setup page: the
    Clipboard API requires a secure context (HTTPS or localhost), which this
    device never serves over, so navigator.clipboard was always undefined and
    the copy button silently failed everywhere. It now falls back to the
    older execCommand('copy') technique, which still works over plain HTTP.
    [web_assets.h]
2026-09-21 Clarify first-run bake selection flow and dough-prep recipe guidance
    The profile picker was buried, collapsed, and labeled "Edit Proof
    Profile" with no visible connection to the guidance card telling
    someone to choose one - confusing for a first-time user with no
    introduction to the device. Renames it to "Choose Your Bake" and
    surfaces it as a real button wherever it's the actual next step.
    - Finish Proof (when nothing further to monitor) and Start New Proof
    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
2026-09-26 Harden distance sensing, add temperature-scaled targets, tidy outcome feedback
    Prompted by a rough night of live monitoring where calibration kept landing
    on bad readings and a slow sourdough ran way behind its fold schedule.
    - Unify live sensor ticks and one-shot calibration captures (Set Empty
    Setup, Set Starting Dough Height) on the same 5-sample, retry-until-valid
    read, instead of a weaker 3-sample no-retry pass for live ticks. Dough is
    a harder target for this sensor than an empty container wall, and the
    two paths had drifted apart in reliability.
    - Add success feedback to Set Starting Dough Height, matching the existing
    Set Empty Setup treatment - pressing it with no confirm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
    [web_assets.h]
2026-09-26 Fix sensor validation, calibration stability, peak-confirm, and target scoping
    Follow-up to a second-opinion code review of tonight's changes, verified
    against the actual installed VL53L0X library and tonight's own live data
    before implementing.
    - Only accept RangeStatus 0 (Range Valid) from the sensor, instead of only
    excluding status 4 (Phase Fail). The other four failure codes (Sigma,
    Signal, Min Range, Hardware) were passing through as if valid whenever
    their garbage distance happened to land in a plausible range.
    - Reject a calibration capture whose 5 samples spread more than 5mm apart,
    instead of accepting any 5 merely-valid readings regardless of whether
    they actually agree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
    [app_state.h, web_assets.h]
2026-09-28 Use long-range sensor mode; loosen calibration spread check to real jitter
    Last night's stricter sensor validation (accept only RangeStatus 0) rejected
    every reading on the real rig: with the default profile, the VL53L0X returned
    all reads at this ~235mm standoff as status 2 (Signal Fail, return too weak),
    so the device never got a valid distance and sat on "Distance reading
    unstable" indefinitely. Confirmed with temporary serial output on the live
    device (40 of 40 reads status 2, then 40 of 40 status 0 after the change).
    - Initialize the sensor in long-range mode, which returns valid status-0
    reads at this rig's standoff, so the strict status check can stay.
    - Raise the calibration sprea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
2026-09-28 Settle window, peak deadband, and pending-fold freeze for rise tracking
    Verified live against a running no-knead bake, including one fold before
    this and one after.
    - Hold rise at the already-earned percentage (0% on a fresh start) for 10
    minutes after Set Starting Dough Height or a completed fold. Smoothing
    the surface, or gathering it for a fold, moves the reading several mm
    while it relaxes back up, which the old code counted as rise and the
    peak then locked in permanently.
    - Require a new peak to clear the old one by more than a distance
    deadband before it's confirmed, landing one deadband under the reading
    rather than banking whatever noise helped it clear the old value.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
    [app_state.h]
2026-09-29 Track confirmed peak for display, cap deadband percentage for shallow doughs
    Verified live on a running Detroit Pizza bake.
    - Displayed rise (and everything derived from it - status text, the
    "hit target already" message, the final recorded percentage) now shows
    the confirmed peak directly instead of max(live reading, peak). The
    live reading was still shown raw whenever it was above the peak, so it
    could visibly climb and fall back on sensor noise - 14% dropping to
    11% before the peak itself ever moved - even though the peak
    underneath was correctly holding steady the whole time.
    - Cap the peak deadband at 4% of rise, not just a flat 3mm. The fixed
    mm value was tuned against a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
2026-09-29 Fix segment clock freezing permanently, protect re-baseline with settle window
    Re-applying the same profile/target (even with nothing changed) called
    resetFermentationEventState(), which zeroed segmentStartedAtMillis while a
    proof was still Running/TargetReached. currentSegmentElapsedSeconds() treats
    0 as "never started" and nothing else re-arms it outside of starting a
    proof, completing a fold, or a settle-release, so this permanently froze the
    segment timer at 0 - visible tonight as the dashboard stuck on "Settling"
    indefinitely. primeEventStateForSelection() now no-ops while a proof is
    actively running.
    Also: manual re-baseline now sets the same settle-and-hold protection a
    fold gets (pr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
    [app_state.h, web_assets.h]
2026-10-01 Scale peak-confirm hold time to dough height, add remote diagnostics, update pretzel recipe
    Detroit Pizza's pan-pressed Final stage (~10mm starting height) let ~2mm of
    ordinary sensor jitter hold for the flat 8-second confirm window and lock in
    a false 15% peak - noise that would only be ~3% of a tall dough's height is
    20%+ of a shallow one's. The confirm hold time now scales up to 90 seconds
    as starting height drops toward 15mm, giving transient noise more time to
    revert before a peak is trusted, while tall doughs keep the fast 8-second
    confirm. Exact scaling constants are a first-pass estimate from tonight's
    Set Empty repeatability data (glass ~1mm spread vs. metal pans ~3mm), not
    yet vali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
2026-10-01 Ignore KiCad's local-history snapshots
    KiCad's built-in backup feature writes periodic snapshots (with its own
    nested git repo) into a .history/ folder under each project directory -
    useful locally, but not something that belongs in version control.
2026-10-05 Fix Cinnamon Rolls bulk target, add feel-test to finish message
    On a live bake the Cinnamon Rolls bulk was judged ready at about 100%
    (visibly doubled), while the temperature-scaled target had called it
    reached at about 39%. The 65% base was an unverified first-commit default
    and the sensor reads air temperature, not dough temperature, so scaling
    over-corrected an enriched dough. Base is now 100 and Cinnamon Rolls is no
    longer in the temperature-scaled recipe list (this also applies to its
    Final stage). Fold triggers are unchanged: spacing them evenly in rise
    percent would assume a linear rise, which results show it isn't.
    The target-reached message now accepts an optional per-recipe extra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
2026-10-06 Add Scali Bread preset (bulk only, braided final left untracked)
    King Arthur's Scali Bread is a commercial-yeast dough with a clear
    "just about doubled" bulk cue, no folds, and an overnight stiff
    preferment made before mixing. Bulk target is 90, matching the other
    yeast recipes that use a doubled cue. The braided free-standing final loaf
    is a poor shape for the downward-facing sensor, so it has no tracked final
    stage and instead points back to the recipe. A premix note covers the
    overnight preferment.
2026-10-06 Rebuild browser installer firmware as 0.1.5-preview
    Includes the new Scali Bread preset. The 0.1.4-preview images were never
    deployed (the Pages run for them stalled during a GitHub Actions outage),
    so this build supersedes them. Only firmware.bin and the version metadata
    changed.
2026-10-07 Stop cold rooms raising targets, smooth the scaling temperature, flag stalled rises
    On a live no-knead bake the first fold trigger drifted from 18.5% to 20.8%
    as the container air cooled, while the dough gained only about 4 points in
    46 minutes, so the goalpost receded nearly as fast as the dough advanced
    and the dough sat flat for an hour with nothing on screen saying so.
    - Temperature scaling is now clamped to 1.0-2.5x instead of 0.5-2.5x:
    warmth can lower a target or fold trigger, but a cold room can never
    raise it above the recipe's authored number. Applies to the target and
    folds together.
    - Scaling now follows a slow average of the air temperature (roughly an
    hour) instead of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
    [app_state.h]
2026-10-07 Rebuild browser installer firmware as 0.1.6-preview
    Includes the cold-room scaling floor, the smoothed scaling temperature,
    and the "Rise has slowed" message, on top of the Scali Bread preset from
    0.1.5-preview. Only firmware.bin and the version metadata changed.
